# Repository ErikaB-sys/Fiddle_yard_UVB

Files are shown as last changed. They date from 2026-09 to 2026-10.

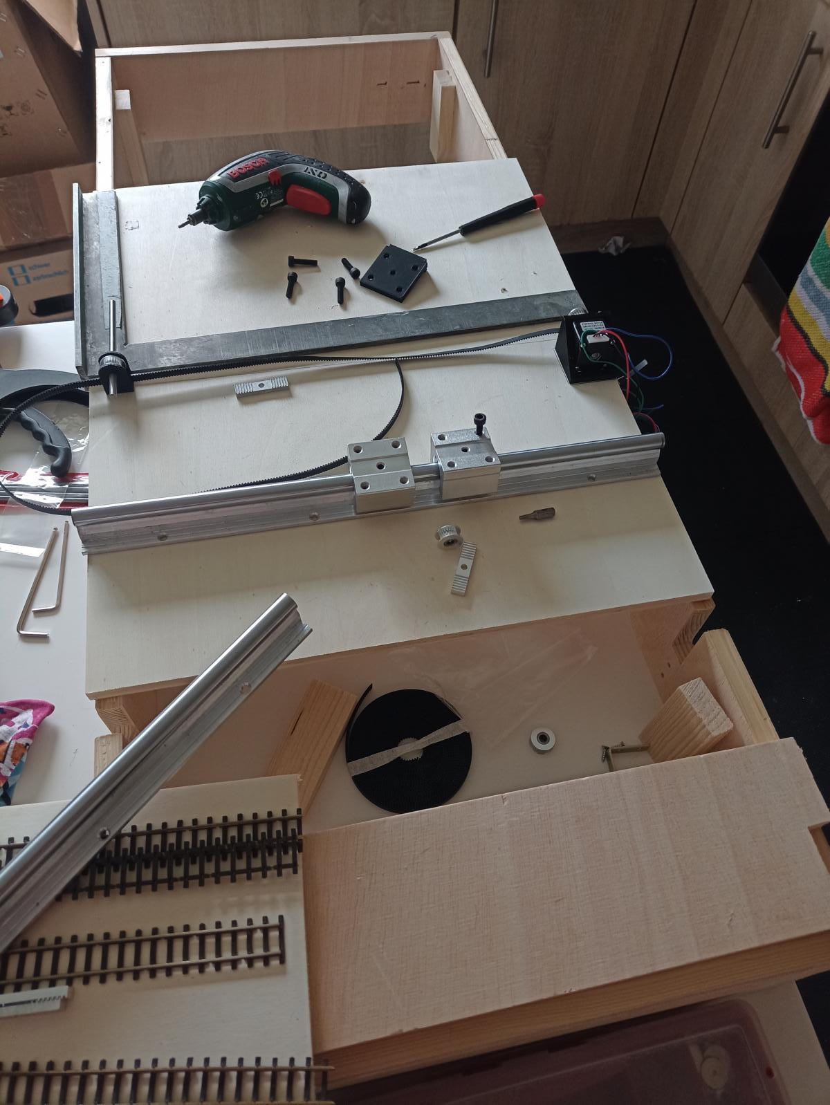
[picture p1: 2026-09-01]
Documents/Pictures/K1600/1000129678.JPG

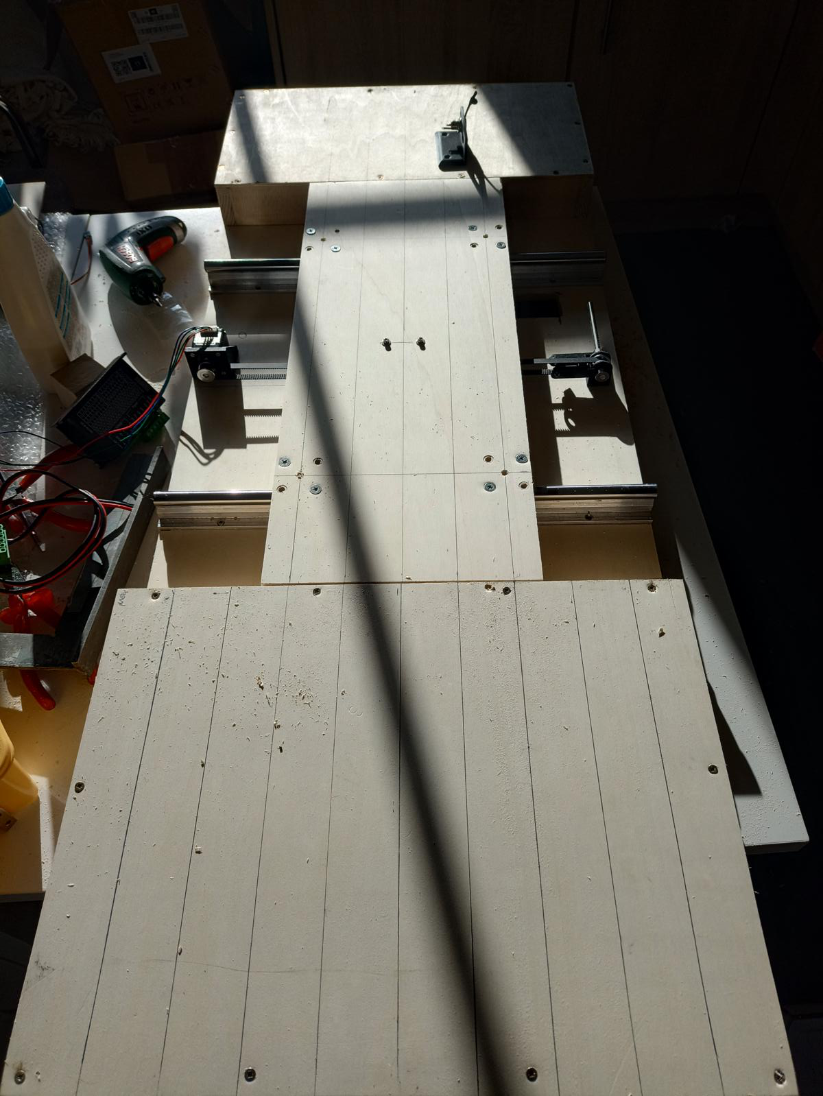
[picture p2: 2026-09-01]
Documents/Pictures/K1600/1000129823.JPG

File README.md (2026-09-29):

# Fiddle_yard_UVB
## Soft and Hard ware for a Fiddleyard with sliding platform 

- Project Language : English / german 
- Usage:  for privat use only

## Coding language 
- C
- C++

## Mechanical design
- FreeCAD 1.0

## Electronic design
- KiCad

## Documents
- PDF
- LibreOffice
- FreeMind
- Mermaid — flowcharts, state diagrams and architecture documentation
- Doxygen — investigate as code-based documentation system for source-code documentation

### Documentation concept
Investigate a documentation workflow combining:
- **Mermaid** for flowcharts, state machines and software architecture diagrams, preferably stored as source in the repository and rendered where possible.
- **Doxygen** for generating technical source-code documentation from structured comments in the C/C++ code.
- **GitHub/Markdown** as the central, version-controlled documentation layer.

The goal is to keep diagrams and technical documentation close to the actual source code and maintainable together with the project.

**Open item:** Add the Doxygen/tool reference supplied by Vincent when available.

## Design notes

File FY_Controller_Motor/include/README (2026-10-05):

This directory contains project-wide header files.

The headers are separated by responsibility:

include/
├── HW_Config.h   - fixed hardware configuration
├── FY_System.h   - FY-specific system data, states and structures
├── Firmware.h    - firmware identity data
├── Main.h        - intentionally empty
└── Protokoll.h   - UART protocol definitions

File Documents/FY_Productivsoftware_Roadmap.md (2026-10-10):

# FY Produktivsoftware – technische Roadmap

**Aktiver Entwicklungsbranch:** `FY_Command_and_Responses`  
**Basis:** aktueller, kompilierbarer Stand von `main`  
**Phasenziel:** UART-Befehle und Antworten vervollständigen, Protokoll und Handler konsistent machen und die Implementierung gezielt testen. Nach erfolgreicher Abschlussprüfung wird die Phase nach `main` gemergt.

> Arbeitsdiagramm für die schrittweise Überführung der Erkenntnisse aus dem FY_HW_TEST in die Produktivsoftware.

```mermaid
flowchart TD
    A["HW-Test Erkenntnisse<br/>#105"] --> B["Motor / Profil<br/>#104"]
    V["Firmware-Identität<br/>#107/ DONE"] -. Build-/Diagnosebasis .-> B

    B --> C["UART / Intermediate Commands<br/>#13"]
    C --> D["Erstes Positions-Command / Motor-Schnittstelle<br/>#28"]
    D --> E["Parameter / Profilwerte<br/>#106 + #104"]
    E --> F["Motorbewegung / Execution / STEP<br/>#51"]

    F -. parallel .-> T["Tests / Native<br/>#46 + PC-Tests"]
    F --> G["Motorzustand / Sicherheit<br/>#86 + #26 + #50 + #52"]
    G --> H["Sensoren<br/>#93"]
    H --> I["Referenz<br/>#85 + #94"]
    I --> J["Position / Trackmodell<br/>#11"]
    J --> K["Keyboard / LOCAL<br/>#88 + #89"]
    K --> L["Display<br/>#90"]
    K --> M["UART / Service<br/>#13 + #17 + #28 + #29 + #39"]
    L --> N["LOCAL / REMOTE<br/>#91"]
    M --> N
    M -. Service .-> S["Servicebetrieb<br/>#95"]
    N --> O["System Executive<br/>#96"]
    O --> P["Gesamtintegration<br/>#30 + Tests"]

    T -. Validierung .-> G
    T -. Validierung .-> I
    T -. Validierung .-> J
    T -. Validierung .-> P
```

## Arbeitsreihenfolge

Die Motorintegration wird bewusst in kleinen, testbaren Schritten aufgebaut. Die echte Hardware ist dabei zunächst **nicht erforderlich**; die Produktivsoftware wird auf dem Schreibtisch-Mockup entwickelt und geprüft.

1. **Firmware-Identität** als kleine Build-/Diagnosebasis festlegen.
2. **Motor-/Profil-Erkenntnisse aus dem HW-Test** übernehmen, ohne den HW-Test-Code zu kopieren.
3. **Intermediate Commands** zuerst produktiv stabilisieren. Damit wird die Kommunikation CMD → Verarbeitung → Response unabhängig von echter Motorbewegung überprüfbar.
4. **Erstes Positions-Command / Motor-Schnittstelle** einführen. Zunächst reicht die Verbindung bis zur Motorlogik bzw. zum Mockup; die vollständige STEP-Ausführung folgt später.
5. **Parameter- und Profilmodell** schrittweise festlegen. Als Startpunkt werden die im HW-Test verifizierten und veränderbaren Parameterwerte verwendet. Die endgültige Klassifizierung von Default-, Konfigurations-, Kalibrier-, Laufzeit- und Diagnosewerten erfolgt in #106.
6. **Motorbewegung / Execution / STEP** in die Produktivsoftware überführen. Die verifizierte Profilberechnung aus #104 und die STEP-Ausführung aus #51 werden dabei getrennt gehalten: Profil berechnet, Execution führt aus.
7. **Mockup vollständig gegen die Produktivschnittstellen testen.**
8. Erst wenn Kommunikation, Position, Parameter und Motor-Execution auf dem Mockup funktionieren, erfolgt der **erste Live-Test mit Steppertreiber und echter Motor-Hardware**.
9. Danach Motorzustand, Sicherheit, Sensoren und Referenz schrittweise ergänzen.
10. Erst auf diesem stabilen Kern folgen Bedienung, Service und Systemintegration.

## Arbeitsprinzip

- Die drei Command-Klassen werden bewusst nacheinander genutzt: **INTERMEDIATE → Positions-/Bewegungsauftrag → weitere ausführende Commands**.
- Kommunikation wird vor echter Motorbewegung stabilisiert.
- Das erste Positions-Command bildet die Brücke zwischen UART und Motor-Schnittstelle.
- Parameter werden zunächst aus dem HW-Test übernommen, aber ihre endgültige Struktur wird nicht vorweggenommen.
- Die reale Hardware dient erst dann als Integrationsprüfung, wenn die Produktivlogik auf dem Mockup nachvollziehbar funktioniert.
- Der Steppertreiber ist eine nachgelagerte Hardware-Schnittstelle; seine konkrete Implementierung wird nicht zum Vorab-Gegenstand der Motor-API gemacht.
- Der HW-Test-Code wird nicht kopiert.
- Übernommen werden bestätigte Anforderungen, Zustände, Abläufe, Parameter und technische Prinzipien.
- UART bleibt bei jedem Entwicklungsschritt funktionsfähig, damit der Nano weiterhin beobachtet und getestet werden kann.
- Referenzkompensation zunächst nicht erzwingen; die Architektur dafür bleibt offen.
- Parameter und EEPROM werden in #106 schrittweise klassifiziert.
- `response()` der Produktiv-UART wird im Zuge der UART-Überarbeitung konkretisiert.
- Neue Issues nur anlegen, wenn aus der Umsetzung tatsächlich eine Lücke entsteht.
- Die Firmware-Identität wird zentral gepflegt: Release-Version manuell, Builddatum/-zeit und Git-Commit automatisch aus dem Build ableiten.

## Gemeinsame Software-Komponenten und Versionierung

Gemeinsame Dateien oder Bibliotheksbestandteile zwischen HW-Test und Produktivsoftware sind grundsätzlich zulässig, wenn sie tatsächlich ein gemeinsames Verfahren oder einen gemeinsamen Mechanismus beschreiben. Das gilt insbesondere für hardwarefreie Berechnungen oder eindeutig definierte Datenstrukturen.

Dabei gilt:

- Eine gemeinsame Datei ist eine **gemeinsame Software-Komponente**, nicht automatisch Bestandteil jeder Firmware-Version.
- Änderungen an einer gemeinsamen Komponente dürfen **keine stille Verhaltensänderung** in einem anderen Projekt erzeugen.
- Die Übernahme einer geänderten gemeinsamen Komponente in eine Firmware muss deshalb **bewusst und nachvollziehbar** erfolgen.
- Die verwendete Version bzw. der konkrete Git-Stand der Komponente muss aus dem jeweiligen Projektstand nachvollziehbar sein.
- Eine Änderung der gemeinsamen Komponente wird zunächst isoliert geprüft. Erst danach wird sie in die jeweils betroffenen Firmwarebereiche übernommen.
- Wenn HW-Test und Produktivsoftware fachlich auseinanderlaufen, darf eine gemeinsame Datei aufgelöst werden. Beide Projekte erhalten dann bewusst eigene Implementierungen.
- **Submodule oder Subrepositories werden dafür nicht vorausgesetzt.** Die gemeinsame Komponente kann im selben Repository liegen; entscheidend ist die nachvollziehbare Übernahme und nicht die technische Verpackung.
- Vor einer Änderung an `FY_Common` wird daher geprüft, welche Projekte die Komponente tatsächlich verwenden und ob eine gemeinsame Weiterentwicklung noch sinnvoll ist.

Für `FY_Common/MotorProfile.h` ist damit zunächst **keine automatische gemeinsame Weiterentwicklung festgelegt**. Vor der nächsten Änderung wird geklärt, ob die Profilberechnung weiterhin eine echte gemeinsame Komponente sein soll oder ob HW-Test und Produktivsoftware an diesem Punkt bewusst getrennte Wege gehen.

## Branch- und Merge-Regel

`main` ist die maßgebliche Referenz für den aktuellen Produktivstand. Die jeweils laufende Implementierungsphase erhält einen eigenen, klar benannten Branch, der aus dem aktuellen `main` erstellt wird. Es wird nicht parallel auf mehreren Produktiv-Branches gearbeitet.

**Aktuelle Phase:** `FY_Command_and_Responses`  
**Ausgangsbasis:** der aktuelle, kompilierbare Stand von `main` mit den bewusst akzeptierten `unused`- und MISRA-Warnings.

Ziele der Phase:

1. Command- und Response-Definitionen mit der tatsächlichen Implementierung abgleichen und vervollständigen.
2. Telegrammlängen, Parameter, Handler und Fehlerantworten konsistent machen.
3. Verfügbare native Tests und gezielte Protokolltests ausführen; nicht ausgeführte Prüfungen ausdrücklich offenhalten.
4. Relevante Issues und Implementierungsstatus aktualisieren.
5. Einen kompilierbaren, überprüften Zwischenstand ohne bekannte Blocker für die abgeschlossene Phase erreichen.

Nach Abschlussprüfung wird `FY_Command_and_Responses` gezielt nach `main` gemergt. Danach wird die nächste Implementierungsphase – voraussichtlich `FY_Motor` – aus dem dann aktuellen `main` erstellt. Der bisherige Branch `FY_Controller_Motor` bleibt als historischer Entwicklungsstand erhalten und wird nicht gelöscht.

Vor jeder Übernahme werden Commit-Historie, relevante Issues und bewusste Architekturentscheidungen geprüft. Eine Abweichung zwischen Branches gilt nicht automatisch als Fehler. Bereits bewusst in `main` vorgenommene Änderungen werden respektiert; es werden nur tatsächlich relevante Unterschiede als offene Punkte gemeldet.

Vor jedem neuen Arbeitsabschnitt werden aktiver Branch und Ausgangscommit geprüft und benannt. Es wird nicht stillschweigend zwischen unterschiedlichen Branch-Ständen gewechselt.

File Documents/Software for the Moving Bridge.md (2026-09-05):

 # Software for the Moving Bridge

**Hardware:** ESP32

**Software components (under development):**

01  Architecture / State Machine
02  UART – Command Interface
03  UART – State Interface

04  Motor Control – Step/Direction/Enable
05  Movement Control – Positioning
06  Movement Control – Acceleration/Deceleration
07  Movement Control – ISR
08  Movement Control – Position Table

09  Reference Sensor
10  Limit / Border Sensor
11  Error Handling
12  Startup and Recovery

13  Button Module – Input Handling
14  Button Module – Commands

15  OLED – Basic Driver
16  OLED – Motor Position
17  OLED – Track Position
18  OLED – State
19  OLED – Error Screen

20  Configuration Storage

21  Web Interface – Status
22  Web Interface – Movement
23  Web Interface – Configuration

24  MQTT – Topic Structure
25  MQTT – Command
26  MQTT – State

27  DCC Detection [OPTIONAL]
28  Track Control [OPTIONAL]

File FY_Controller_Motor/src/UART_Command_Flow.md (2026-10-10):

# UART Commands – Ablauf und Antwortbedingungen

Referenz für die Protokollabstimmung in [Issue #58](https://github.com/ErikaB-sys/Fiddle_yard_UVB/issues/58).
Die Übersicht unterscheidet bereits implementierte Antwortpfade von noch offenen Handlern.

## Zentrale Übersicht

```mermaid
flowchart TD
    A[ASCII-Eingabe] --> B[BabelFish dekodiert Command]
    B --> C{Command erkannt?}
    C -- Nein --> N1[NACK: ungültige Eingabe]
    C -- Ja --> D[Validierung: Command-ID, DATA-Länge, CRC]
    D --> E{Validierung erfolgreich?}
    E -- Nein --> N2[NACK: ungültiges Telegramm]
    E -- Ja --> F{Command-Typ}
    F -- IMMEDIATE --> G[GET / HELP / FIRMWARE Handler]
    G --> R1[Passende STATUS-Antwort]
    F -- EXECUTE --> H{System Busy?}
    H -- Ja --> N3[NACK mit Command-ID]
    H -- Nein --> I{Execute-Command}
    I -- SET_MODE --> M[SET_MODE Handler]
    M --> M1{Daten und Zustand gültig?}
    M1 -- Ja --> ACK[ACK mit Command-ID]
    M1 -- Nein --> N4[NACK mit Command-ID]
    I -- Andere Execute-CMDs --> T[Antwortverhalten je Handler prüfen]
    F -- PRIORITY --> P[Priority-Handler]
    P --> R2[Antwort gemäß Command-Definition]
```

## SET_MODE – Detailablauf

```mermaid
flowchart TD
    A[CMD_SET_MODE, DATA-Länge 2] --> B{Systemstatus, Keyboard und Motor verfügbar?}
    B -- Nein --> N[NACK, keine Zustandsänderung]
    B -- Ja --> C{System Busy oder Motor bewegt sich?}
    C -- Ja --> N
    C -- Nein --> D{DATA = 55 AA?}
    D -- Ja --> L[System Mode = LOCAL\nKeyboard mirrors system mode]
    D -- Nein --> E{DATA = AA 55?}
    E -- Ja --> R[System Mode = REMOTE\nKeyboard mirrors system mode]
    E -- Nein --> N
    L --> ACK[ACK mit Command-ID]
    R --> ACK
```

## SET_MODE – Bedingungen

| Bedingung | Antwort | Zustandsänderung |
|---|---|---|
| Erforderliches Modul fehlt | NACK | keine |
| System meldet Busy | NACK | keine |
| Motor bewegt sich | NACK | keine |
| DATA `55 AA` | ACK | `FY_SystemStatus_t.mode = LOCAL`; keyboard mirrors mode |
| DATA `AA 55` | ACK | `FY_SystemStatus_t.mode = REMOTE`; local movement/OK inputs locked, STOP remains available |
| Anderes DATA-Muster | NACK | keine |

- Command-ID: `CMD_SET_MODE = 0x26` (bisherige SET_LOCAL-ID weiterverwendet).
- DATA-Länge: 2 Byte.
- `CMD_SET_LOCAL` und `CMD_SET_REMOTE` entfallen; die alte ID `0x2A` wird nicht mehr verwendet.
- ACK (`0x60`) und NACK (`0x70`) enthalten jeweils die Command-ID als ein DATA-Byte; die CRC folgt wie üblich.
- Die maßgebliche Betriebsart liegt in `FY_SystemStatus_t.mode`; das Keyboard spiegelt sie für Anzeige und lokale Eingabesperre.
- SET_MODE schaltet den Motor nicht ein und startet keine Bewegung.
- Der Wechsel ist nur im Stillstand zulässig.

## Noch offene Handler

Die zentrale Übersicht ist keine Behauptung, dass alle Command-Handler bereits vollständig implementiert sind. STOPP bleibt gemäß aktueller Arbeitsabsprache zurückgestellt. Die Antwortpfade der übrigen Execute-Commands werden zusammen mit deren tatsächlicher Implementierung abgeglichen. GET-Antworten richten sich nach den vorhandenen Response-Definitionen und werden mit den Modulen vervollständigt.

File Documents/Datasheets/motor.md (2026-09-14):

Motor:
  Type: Nema 17
  Manufacturer:  	Iverntech 

Electrical:
  Rated voltage: 3.8 V DC
  Rated current:  0.8 A
  Phase resistance: 4,8Ohm 10%
  Phase inductance: 2,8 mH 20%

Mechanical:
  Step angle:       1,8°
  Holding torque:   min. 6.5Ncm
  Rotor inertia:    7,5g gcm^²

Speed/Torque:
  Torque curve:          ?
  Max recommended speed: ? 	28 Umdrehungen pro Minute

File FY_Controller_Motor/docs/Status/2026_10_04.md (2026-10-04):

# FY UVB – Projektstatus

**Stand: 04.10.2026**

## 1. Management Summary

Seit dem letzten Status vom **25.09.2026** hat sich der Schwerpunkt erneut verschoben:

> **Die Hardware-Testsoftware #84 ist abgeschlossen. Die reale Hardware funktioniert grundsätzlich. Der nächste Hardware-Meilenstein ist jetzt der Vergleich mit dem neuen Motor.**

Der Hardware-Smoke-Test hat damit seine Aufgabe erfüllt: Sensoren, ENABLE/DIR/STEP, Timer1-Testbetrieb und die grundlegende Motor-/Treiberkette sind praktisch nachgewiesen.

Parallel hat sich der **Produktivcode deutlich weiterentwickelt**, vor allem auf der UART-Seite:

- UART #13 ist inzwischen **geschlossen**.
- Command-Telegramme, Längenprüfung, CRC und ResponsePending/Response-Fluss sind wesentlich weiter.
- Die Verbindung **UART → MotorJob → Motor.setJob()** ist als Architektur vorhanden.
- Die fachliche Trennung **validateCommand() → prepare...() → setJob()** ist inzwischen festgelegt.
- calcProfile() #23 ist abgeschlossen.
- Die aus dem HW-Test gewonnenen Erkenntnisse werden jetzt gezielt in die Produktivsoftware überführt (#104/#105).
- Firmware-Identität #107 ist abgeschlossen.
- Ein neues Parameter-/Kalibrierungsmodell #106 ist angelegt.
- Die neue Motorvariante #109 und die per Arduino schaltbare Microstep-Stufe #110 sind zusätzliche Hardware-Randbedingungen, aber **kein Grund, die Motorarchitektur erneut aufzureißen**.

Der wesentliche Befund für die Roadmap lautet:

> **Die bisherige Roadmap ist fachlich weiterhin richtig, aber die Reihenfolge muss von einer linearen UART→Motor-Entwicklung zu einer parallelen Integrations-Roadmap angepasst werden.**

UART ist nicht mehr der Engpass. Der Engpass ist jetzt eindeutig:

```text
MotorJob
   ↓
prepare...
   ↓
State Machine
   ↓
Timer1 / STEP
   ↓
Position
   ↓
Reference
```

Danach folgt die Systemintegration.

---

## 2. Status nach Hauptmodulen

| Modul / Bereich | Status | Bewertung |
|---|---|---|
| FY_HW_Test #84 | 🟢 abgeschlossen | Hardware-Smoke-Test erfüllt seinen Zweck |
| Sensorhardware | 🟢 | Lichtschranken mechanisch montiert und praktisch bestätigt |
| Motor-Hardwarepfad | 🟢/🟡 | Motor läuft grundsätzlich; Laufkultur/Strom/Spannung werden noch untersucht |
| neuer Motor #109 | 🟡 | bestellt, Halter wird vorbereitet, Vergleichstest folgt |
| Microstepping #110 | 🟡 | neue Platine kann künftig umschalten; 1/4 bleibt zunächst Referenz |
| UART #13 | 🟢 abgeschlossen | Empfang, Validierung, CRC und Response-Fluss weitgehend fertig |
| UART Robustheit #17 | 🟡 | verbleibende Detail-/Sicherheitsfragen |
| UART → Motor #28 | 🟡 | Schnittstelle vorhanden, vollständige Laufzeitintegration fehlt |
| calcProfile() #23 | 🟢 abgeschlossen | mathematische Profilberechnung produktiv vorhanden |
| HW-Erkenntnisse → Produktivcode #104/#105 | 🟡 | laufende Übergangsphase |
| Parameter/Kalibrierung #106 | 🟡 | neu angelegt, vorläufige Grundlage |
| Motor ON/OFF #86 | 🟡 | fachlich definiert, produktive Umsetzung offen |
| prepare... #24 | 🟡 | fachlich spezifiziert, produktive Umsetzung als nächster Motorblock |
| State Machine #50 | 🔴 | noch nicht fertig |
| Timer1 / STEP / ISR #51 | 🔴 | Architektur definiert, produktiver Executor offen |
| Position / Status #52 | 🔴 | Schnittstelle definiert, produktive Positionsführung offen |
| Reference #27 | 🟢 fachlich / 🔴 technisch | Spezifikation abgeschlossen, Implementierung offen |
| Switches #93 | 🟡 | Rohzugriff/ISR-Architektur definiert |
| System Executive #96 | 🟡 | Architektur angelegt, Implementierung noch nach Motorgrundfunktion |
| Keyboard / OLED | 🟢 Basis / 🟡 Integration | Modul vorhanden, Systemanbindung offen |
| POR #94 | 🟢 spezifiziert/geschlossen | Systemablauf definiert, technische Abhängigkeiten bestehen noch |
| Tests #59/#60–#71 | 🟡 | Struktur vorhanden, konkrete Implementierung folgt mit den Produktivblöcken |
| Dokumentation | 🟢/🟡 | gute Basis, muss mit dem Produktivstand synchronisiert bleiben |

---

## 3. Hardware: #84 ist fertig

Der separate **FY_HW_Test** hat seinen Zweck erfüllt.

Nachgewiesen sind insbesondere:

- Controller-/I²C-Hardware
- Taster und LEDs
- OLED
- Lichtschranken / Endsensoren
- Referenzfahnen
- ENABLE
- DIR
- STEP
- Timer1-basierte Testbewegung
- Endschalter-Sperre im Testbetrieb
- Motorbetrieb ohne mechanische Kopplung
- grundlegende mechanische Funktion

Damit ist #84 **nicht mehr Teil der eigentlichen Produktentwicklungs-Roadmap**.

Der Testcode bleibt als Werkzeug erhalten, aber wir müssen dort nicht mehr künstlich weiterentwickeln.

---

## 4. Hardware-Kurzradar

Die verbleibenden Hardwarefragen sind bewusst klein.

### Neuer Motor #109

Der neue Motor wird zunächst gegen den bisherigen Aufbau getestet.

Geplant:

```text
Motorhalter
   ↓
neuer Motor
   ↓
gleicher Treiber
   ↓
etwas höherer Strom
   ↓
ggf. etwas höhere Versorgungsspannung
   ↓
Laufverhalten vergleichen
```

Ziel ist zunächst nicht eine endgültige Optimierung, sondern die Frage:

> **Bringt der stärkere Motor bei sinnvoller Ansteuerung tatsächlich einen praktischen Vorteil?**

### Microstepping #110

Die neue Platine erlaubt später die Umschaltung der Microstep-Stufe.

Für die Produktentwicklung bleibt zunächst:

**1/4 Schritt = Referenzkonfiguration.**

Andere Stufen sind zunächst Experimentier-/Vergleichswerte.

Damit muss die Motorlogik **nicht** an eine einzelne Microstep-Hardwareverdrahtung gekoppelt werden.

---

## 5. UART – deutlicher Fortschritt

Hier hat sich die Lage gegenüber dem letzten Status stark verändert.

### UART #13

**🟢 abgeschlossen**

Die wichtigsten Schritte wurden inzwischen umgesetzt:

- Command-Längen korrigiert
- Command-Validierung vervollständigt
- CRC-Prüfung eingebunden
- Validation-Status erhalten
- ResponsePending-Fluss fertiggestellt
- Send-Response-Mechanismus praktisch erprobt

Damit ist UART nicht mehr der technische Hauptengpass.

### Was noch bleibt

#17 bleibt als Robustheits-/Feinschliff-Thema offen.

Außerdem muss die tatsächliche Rückmeldung des Motors später mit den Motorzuständen verbunden werden:

```text
Motor
  ↓
Status / DONE / ERROR
  ↓
UART Response
```

Das ist aber **Integrationsarbeit**, keine neue UART-Grundarchitektur.

---

## 6. UART → Motor

Die ursprüngliche Roadmap hatte hier einen linearen Ablauf:

```text
UART
 ↓
MotorJob
 ↓
Motor
```

Das ist inzwischen als Schnittstelle vorhanden.

Die wichtigere Erkenntnis aus der Arbeit der letzten Tage ist die saubere Verantwortungsverteilung:

```text
UART
 ↓
validateCommand()
 ↓
MotorJob
 ↓
prepare...()
 ↓
setJob()
 ↓
Motor
```

### validateCommand()

Prüft das Telegramm formal: Command, Länge, CRC, formale Datenvalidität.

### prepare...()

Prüft die fachliche Ausführbarkeit: Motor ON, Job, Ziel, Referenz, Grenzen, Profil.

### setJob()

Übernimmt nur einen bereits zulässigen, ausführbaren Auftrag.

> **Diese Trennung ist eine wichtige Architekturentscheidung und sollte nicht wieder aufgeweicht werden.**

---

## 7. Motor – der aktuelle Hauptblock

### #23 calcProfile()

**🟢 abgeschlossen**

Die Profilberechnung ist inzwischen ein echter Produktivbaustein.

Die sechs Segmente bleiben:

```text
ACC1 → ACC2 → KONST → BRE1 → BRE2 → POSI
```

Die Profilmathematik bleibt vollständig außerhalb der ISR.

Die HW-Erkenntnisse haben das Modell inzwischen zusätzlich konkretisiert:

- 1/4 Microstepping als aktuelle Referenz
- obere praktische STEP-Geschwindigkeit etwa 1000 Steps/s
- keine Sprünge auf VMAX innerhalb des Profils
- unabhängige Rampenintervalle
- Profil vollständig vor Bewegungsstart berechnen

Das ist genau der Zweck von #104: **HW-Erkenntnisse übernehmen, ohne HW-Testcode in den Produktivcode zu kopieren.**

---

## 8. #104 / #105 – Übergang HW-Test → Produktivsoftware

Das ist momentan ein **Brückenbereich**, kein eigenständiges Produktmodul.

#105 definiert sinnvoll die vier Kategorien:

- ANPASSEN
- ÜBERNAHME
- NEU
- NICHT ÜBERNEHMEN

Diese Arbeitsweise passt weiterhin.

Besonders wichtig:

> Der HW-Test wird nicht zur zweiten Produktivarchitektur.

Wir übernehmen nur die bestätigten Parameter, Randbedingungen, Zustände, Messwerte und Anforderungen.

Die Test-/Diagnosemechanik bleibt dort, wo sie hingehört.

---

## 9. #24 prepare... – nächster konkreter Motorblock

**🟡 → nächster Umsetzungsschritt**

Die fachliche Reihenfolge steht:

```text
Motor ON?
   ↓
Job
   ↓
Ziel bestimmen
   ↓
Ziel plausibilisieren
   ↓
Referenz prüfen
   ↓
Grenzen prüfen
   ↓
TargetPosition
   ↓
calcProfile()
   ↓
TimerValid
```

Damit ist die Aufgabe inzwischen deutlich kleiner als noch im Status vom 25.09.

Die Profilmathematik ist fertig. Die fachlichen Regeln sind festgelegt.

Jetzt geht es tatsächlich um die Implementierung der vier Prepare-Funktionen und CheckBorder().

---

## 10. #86 Motor ON/OFF

**🟡 fachlich fertig, Implementierung offen**

Die Trennung bleibt verbindlich:

```text
motorEnabled
referenceValid
```

Motor ON bedeutet nur: Motor darf elektrisch betrieben werden.

Motor ON bedeutet **nicht**: Motor ist referenziert.

Motor OFF führt dagegen zum Verlust der gültigen Referenz.

Das ist inzwischen eine klare Voraussetzung für #24.

---

## 11. #50 State Machine

**🔴 offen**

Die State Machine ist jetzt der nächste größere Motorblock.

Sie soll nicht die Bewegungsmathematik enthalten, sondern orchestrieren:

```text
MotorJob
   ↓
prepare
   ↓
MOVING
   ↓
Timer1
   ↓
STOP_BY_PROFILE
        oder
STOP_BY_SWITCH
   ↓
Folgezustand
```

Die bereits festgelegte Trennung zwischen physischem Ereignis und fachlicher Fehlerbewertung bleibt dabei wichtig.

---

## 12. #51 Timer1 / STEP / ISR

**🔴 offen – aber jetzt klar spezifiziert**

Die ISR ist inzwischen fachlich gut eingegrenzt.

**Darf:** STEP erzeugen, DIR ausgeben, Position verändern, Profilsegment wechseln, Endschalter unmittelbar berücksichtigen, physischen Stop melden.

**Darf nicht:** Profil berechnen, UART bedienen, fachliche Fehlerdiagnose durchführen, komplexe Systemlogik ausführen.

Damit ist #51 kein Architekturproblem mehr.

Es ist jetzt eine **Implementierungsaufgabe**.

---

## 13. #52 Position

**🔴 offen**

Die Positionsführung wird direkt mit #51 gekoppelt:

```text
logische Richtung
      ↓
STEP
      ↓
Position +/- 1
```

Wichtig bleibt:

**Die elektrische DIR-Pinpolarität bestimmt nicht die mathematische Bewegungsrichtung.**

Die Zuordnung wird konfigurierbar gehalten.

---

## 14. Reference #27

**🟢 Spezifikation abgeschlossen / 🔴 technische Umsetzung offen**

Die Referenzfahrt ist nicht mehr „noch zu überlegen“.

Sie ist fachlich definiert:

- kurze und lange Referenzierung
- gemeinsame State Machine
- linke/rechte Endlage
- Referenzfahne
- langsame Referenzanfahrten
- Messung aus beiden Richtungen
- Toleranzbewertung
- unabhängige Schritt-/Zeitlimits
- Kalibrierdaten

Damit ist die Arbeit jetzt überwiegend **Implementierung**.

Die reale Sensorhardware ist bereits vorhanden und geprüft.

---

## 15. #106 Parameter- und Kalibrierungsmodell

**🟡 neu / sinnvoll**

Dieses Issue ist eine direkte Konsequenz aus dem HW-Test.

Wir haben inzwischen echte Messwerte und müssen unterscheiden zwischen:

| Kategorie | Beispiel |
|---|---|
| fester Systemwert | Track-Anzahl |
| Default | initiale VMIN/VMAX |
| Konfiguration | veränderbarer Parameter |
| Messwert | Referenzmessung |
| Kalibrierwert | gültige Referenzdaten |
| Laufzeitwert | aktuelle Position |
| Diagnosewert | VMAX_REACHED |

Das Issue sollte **nicht** vorzeitig in eine große EEPROM-Architektur ausarten.

Die fachliche Klassifizierung kommt zuerst.

---

## 16. Systemintegration – neue Gewichtung

Hier hat sich die Roadmap am stärksten verändert.

Früher war der Gedanke:

```text
UART
 ↓
Motor
 ↓
System
```

Heute ist klarer:

```text
          UART
            │
Keyboard ─ System ─ Motor
            │
         Switches
```

und im Motor selbst:

```text
System
  ↓
MotorJob
  ↓
prepare
  ↓
Timer1 ISR
```

Das neue **System Executive #96** ist deshalb sinnvoll.

ABER:

> **#96 ist kein Grund, die Motorimplementierung jetzt zu unterbrechen.**

Der Motor muss erst eine saubere ausführbare Einheit sein.

Danach kann das System Executive die vorhandenen Module zusammenführen.

---

## 17. Keyboard / POR

Hier ist die Situation ebenfalls günstiger als im letzten Status.

#94 **POR – Systemstart, LOCAL und Referenzlauf über Keyboard** ist inzwischen geschlossen.

Das bedeutet nicht, dass der komplette Ablauf technisch schon auf der Hardware läuft.

Es bedeutet:

> **Der gewünschte Systemablauf ist entschieden.**

Damit können wir später die vorhandenen Keyboard-/OLED-Bausteine gegen die tatsächlichen Motorzustände verdrahten.

Das ist genau die richtige Reihenfolge.

---

## 18. Tests – neue Strategie

Die Test-Issues #60–#71 bleiben sinnvoll.

Aber wir sollten sie nicht mehr als riesigen separaten Block vor uns herschieben.

Stattdessen:

```text
Produktivfunktion
      ↓
kleiner Test
      ↓
nächste Produktivfunktion
      ↓
Integrationstest
```

Insbesondere:

- #51 → Timer-/STEP-Test
- #52 → Positions-/Status-Test
- #50 → State-Machine-Test
- #28/#29 → UART/Motor-Integration
- #59 → UART-Modultests

Damit wird die Testarbeit wieder **Teil der Implementierung** statt ein zweites Projekt.

---

## 19. Roadmap-Bewertung

### 🟢 Was weiterhin stimmt

Die grundsätzliche Architektur stimmt weiterhin:

```text
UART / Keyboard
       ↓
    MotorJob
       ↓
    prepare
       ↓
  calcProfile
       ↓
   State Machine
       ↓
   Timer1 / ISR
       ↓
    Position
       ↓
   Reference
       ↓
 System
```

Auch die Trennung **Hardware-Test ≠ Produktivsoftware** ist weiterhin richtig.

### 🟡 Was geändert werden muss

Die Roadmap darf **nicht mehr als lineare Liste „erst UART, dann Motor“** betrachtet werden.

UART ist inzwischen weitgehend fertig.

Der neue Schwerpunkt ist:

### Phase A – Motor ausführbar machen

1. #24 prepare...
2. #86 Motor ON/OFF
3. #50 State Machine
4. #51 Timer1 / STEP / ISR
5. #52 Position

### Phase B – Referenz und Kalibrierung

6. #27 Reference
7. #85 Referenzkorrektur
8. #106 Parameter/Kalibrierung

### Phase C – System

9. #96 System Executive
10. Keyboard/POR-Anbindung
11. UART ↔ Motor ↔ System
12. ACK/BUSY/DONE/ERROR im echten Lauf

### Phase D – Verifikation

13. Modultests
14. Hardware-/Referenztest
15. Track-Betrieb
16. Gesamtintegration

---

## 20. Was NICHT auf die kritische Route gehört

Folgende Themen bleiben bewusst Radar/Backlog:

- ESP32
- Webinterface
- komplexe Diagnose
- Bewegungsanimation
- Step-Servicebetrieb #95
- umfangreiche OLED-Menüs
- BELT_SENSOR
- weitere Abstraktionsschichten
- perfekte Fehlerhistorie

Sie können später sinnvoll werden.

**Sie blockieren den Motor aber nicht.**

---

## 21. Aktuelle kritische Kette

```text
             🟢 UART
                │
                ▼
          🟢 MotorJob
                │
                ▼
          🟡 prepare...
                │
                ▼
          🟢 calcProfile
                │
                ▼
          🔴 State Machine
                │
                ▼
          🔴 Timer1 / ISR
                │
                ▼
          🔴 Position
                │
                ▼
          🔴 Reference
                │
                ▼
          🟡 System
                │
                ▼
          🔴 Gesamtintegration
```

Und daneben:

```text
🟢 Hardware-Smoke-Test
       │
       ├── 🟢 Sensoren
       ├── 🟢 STEP/DIR/ENABLE
       ├── 🟢 Motor grundsätzlich
       │
       └── 🟡 neuer Motor / Parametervergleich
```

---

## 22. Managerfragen – Antworten

### Sind wir auf Kurs?

**Ja.**

Nicht auf dem ursprünglichen Zeitplan im Sinne einer starren Reihenfolge, aber auf der technischen Roadmap.

### Gibt es ein Architekturproblem?

**Nein.**

Im Gegenteil: Die Verantwortlichkeiten sind inzwischen klarer als vor zwei Wochen.

### Gibt es einen technischen Engpass?

**Ja: Motor Execution.**

```text
prepare → State Machine → Timer1 → Position
```

### Ist UART noch kritisch?

**Nein.**

UART ist inzwischen eine belastbare Basis. Die noch offenen Punkte sind überwiegend Integration und Robustheit.

### Ist die Hardware ein Risiko?

**Nur noch begrenzt.**

Der Motor läuft grundsätzlich. Der neue Motor wird jetzt zeigen, ob wir bei Drehmoment/Laufkultur noch etwas verbessern können.

### Müssen wir die Roadmap neu schreiben?

**Nicht komplett.**

Wir müssen sie **neu gewichten und entlinearisieren**.

### Was ist der nächste echte Meilenstein?

> **Eine produktive Bewegungsanforderung läuft von MotorJob über prepare und Profil bis zu einem echten STEP-/Positionsablauf.**

Das ist der nächste große grüne Haken.

---

## 23. Gesamtfazit

Der Projektstand hat sich seit dem letzten Status deutlich verändert.

Am 25.09. war die zentrale Frage:

> **„Kann die Hardware überhaupt laufen?“**

Heute lautet sie:

> **„Wie bringen wir die bereits definierte Produktivmotorlogik jetzt kontrolliert bis zum ersten echten Bewegungsauftrag?“**

Das ist ein qualitativer Fortschritt.

Die Hardware-Testphase ist praktisch abgeschlossen.

UART ist von einem offenen Entwicklungsblock zu einer weitgehend fertigen Kommunikationsbasis geworden.

Die Produktivsoftware hat mit calcProfile() ihren ersten wirklich fertigen Motorbaustein.

Die fachliche Architektur für Prepare, Motorzustand, State Machine, Timer1 und Reference ist weitgehend entschieden.

Damit ist die Roadmap weiterhin tragfähig.

**Die Änderung besteht vor allem darin, dass wir jetzt nicht mehr „UART fertig machen und dann Motor“ arbeiten, sondern den Motor als nächsten Kernpfad fertigstellen und anschließend UART, Keyboard und System Executive darum integrieren.**

Der nächste sinnvolle Arbeitsschritt ist daher sehr unspektakulär:

**#24 – prepare... fertig machen.**

Danach wird es mit #50/#51 erstmals richtig interessant: Dann bekommt unser Produktivcode nämlich die Chance, genau das zu tun, was der Hardwaretest bereits kann – **einen Motor kontrolliert bewegen.**

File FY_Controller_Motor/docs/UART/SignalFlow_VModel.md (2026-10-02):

# UART / Motor – Signal Flow V-Model

Dieses Diagramm beschreibt den Signal- und Funktionsfluss der produktiven Firmware.
Es ist bewusst als wachsende Arbeitsdokumentation angelegt: Mit jedem abgeschlossenen
Arbeitsschritt wird der betreffende Abschnitt präzisiert.

Der Fußpunkt des V ist die Timer1-ISR. Links läuft der Eingang bis zur Ausführung
hinunter, rechts entsteht daraus wieder der Status-/Antwortweg nach oben.

## V-Modell

```mermaid
flowchart TB

    subgraph LEFT["Eingang / Auftrag"]
        L0["Host / ESP32 / Terminal"]
        L1["Serial RX"]
        L2["UART::receive()"]
        L3["BabelFish::process()\nASCII → Binär + CRC erzeugen"]
        L4["CommandBuffer"]
        L5["UART::validateCommand()\n1. CMD-ID\n2. Telegrammlänge\n3. CRC"]
        L6["decodeCommand()\nCommand seiner Verarbeitung zuordnen"]
        L7["SetCommand() / MotorJob_t"]
        L8["Motor::prepare...()\nMotorseitige Ausführbarkeit"]
        L9["Motor::setJob()\nvaliden Job übernehmen"]
        L10["calcProfile()"]
    end

    subgraph RIGHT["Antwort / Ergebnis"]
        R10["Motorzustand / Ergebnis"]
        R9["ResponseBuffer"]
        R8["UART::sendResponse()"]
        R7["Serial TX"]
        R6["Host / ESP32"]
    end

    L0 --> L1 --> L2 --> L3 --> L4 --> L5 --> L6 --> L7 --> L8 --> L9 --> L10
    L10 --> ISR["Timer1 ISR\nSTEP / Position / Profil"]
    ISR --> R10 --> R9 --> R8 --> R7 --> R6

    style ISR stroke-width:3px
```

## Arbeitsprinzip

### Linke Seite – Eingang

Die linke Seite wird von oben nach unten schrittweise fertiggestellt:

1. UART-Empfang
2. BabelFish: ASCII → Binärtelegramm und CRC erzeugen; keine semantische Command-Validierung
3. `validateCommand()`: Command-ID, Telegrammlänge und CRC prüfen; später weitere formale Telegrammprüfungen
4. Command-Zuordnung und Behandlung
5. Motorvorbereitung
6. `setJob()`
7. Profilberechnung
8. ISR-Ausführung

### Fußpunkt – ISR

Die ISR ist der Ausführungskern des V:
- STEP erzeugen
- Position fortschreiben
- Profilsegment ausführen
- Endbedingungen erkennen

Die ISR entscheidet nicht über die Bedeutung eines UART-Kommandos.

### Rechte Seite – Antwort

Die rechte Seite wird aufgebaut, sobald Ausführung und Ergebnisse definiert sind:
- Motorzustand / Ergebnis
- Response-Daten
- `sendResponse()`
- Serial TX
- Rückmeldung an Host / ESP32

## Aktueller Arbeitsstand

| Abschnitt | Status |
|---|---|
| UART → BabelFish → CommandBuffer | erledigt |
| Command-Lifecycle / UART Busy | erledigt |
| Command-ID prüfen | vorhanden |
| Telegrammlänge prüfen | vorhanden |
| **CRC in `validateCommand()` prüfen** | **nächster Arbeitsschritt** |
| Command-Zuordnung / Behandlung | danach |
| MotorJob / Motor-Schnittstelle | danach |
| Profil / ISR-Anbindung | später |
| Antwortweg vollständig definieren | wird ergänzt |

## Dokumentationsregel

Dieses Diagramm ist keine zweite Protokollspezifikation. Die konkreten Command-Definitionen
bleiben in `Protokoll.h`, die Implementierung bleibt in den jeweiligen Modulen.

Das Diagramm dokumentiert ausschließlich:
- welche Funktion als Nächstes aufgerufen wird
- welche Aufgabe sie besitzt
- welche Daten dabei weitergegeben werden
- wo im V-Modell der aktuelle Entwicklungsstand liegt.

Bei längeren Unterbrechungen soll damit ohne erneutes Durcharbeiten des gesamten Codes
erkennbar sein, wo der Signalfluss zuletzt abgeschlossen wurde.

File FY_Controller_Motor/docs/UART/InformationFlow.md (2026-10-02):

# UART – Information Flow

This document describes the information path through the productive UART architecture.

It is intentionally a **flow document**, not a second protocol specification. Command definitions remain in Protokoll.h; module behaviour remains in the respective modules.

## 1. End-to-end flow

```mermaid
flowchart LR
    A["Host / Terminal<br/>ASCII command"] --> B["Serial"]
    B --> C["UART::receive()"]
    C --> D["BabelFish"]

    D -->|ASCII → binary| E["CommandBuffer.command"]
    D -->|invalid line| X["CMD_INVALID"]

    E --> F["validateCommand()"]
    F -->|invalid| Y["DATA_INVALID"]
    F -->|valid| G["commandReady"]

    G --> H["UART::update()"]
    H --> I["decodeCommand()"]

    I -->|IMMEDIATE| J["Status / information handler"]
    I -->|EXECUTE| K["SetCommand()"]
    I -->|PRIORITY| L["Priority handler"]

    K --> M["Motor::setJob()"]
    M --> N["Motor"]

    J --> O["ResponseBuffer"]
    L --> O
    M --> O
    X --> P["NACK"]
    Y --> P

    O --> Q["sendResponse()"]
    P --> Q
    Q --> R["Serial TX"]
    R --> A
```

## 2. Where errors belong

```mermaid
flowchart TD
    A["ASCII / transport"] --> B["BabelFish"]
    B -->|syntax / command text invalid| C["CMD_INVALID"]

    B --> D["Binary command"]
    D --> E["UART validation"]
    E -->|telegram data invalid| F["DATA_INVALID"]

    E --> G["Command accepted by UART"]
    G --> H["Command dispatch"]

    H --> I["System / Motor preconditions"]
    I -->|not allowed| J["Command rejection / error"]

    I --> K["Motor execution"]
    K -->|runtime fault| L["Execution / system error"]

    J --> M["Response"]
    L --> M
```

The important architectural distinction is:

- **BabelFish errors** concern the textual command representation.
- **UART validation errors** concern the decoded command and its telegram definition.
- **System / Motor errors** concern whether a valid command may be executed.
- **Execution errors** concern faults occurring after execution has started.

These categories can later be mapped to the system-wide error definitions without changing the information flow.

## 3. Command lifecycle

```mermaid
stateDiagram-v2
    [*] --> Receive
    Receive --> CommandReady: complete / invalid line
    CommandReady --> Processing
    Processing --> Receive: response sent

    note right of CommandReady
        UART mailbox locked
        No second command accepted
    end note
```

This lifecycle is deliberately independent of the Motor state.

**UART busy** means only that one command is currently owned by the UART command lifecycle. It is not the same as FY_SystemState_t::Busy or MotorState_t::MOVING.

## 4. Architectural invariants

1. UART::receive() is the single owner of Serial input.
2. BabelFish processes characters supplied by UART; it does not own Serial.
3. The existing CommandBuffer remains the command hand-off point.
4. commandReady prevents overwriting a command while it is being processed.
5. Invalid commands follow the same lifecycle and release the UART afterwards.
6. decodeCommand() dispatches; it does not become a second Motor implementation.
7. Motor-specific execution remains in the Motor module.
8. No additional intermediate command class is introduced.

## 5. Related documentation

- ReceiveFlow.md – character reception and command lifecycle
- SetCommandFlow.md – UART → Motor job hand-off
- ClassDiagram.md – module relationships
- ../System/ModuleStates.md – system and module states
- ../System/FY_System_Executive.md – overall system scheduling

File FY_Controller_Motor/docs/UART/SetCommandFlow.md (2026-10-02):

# UART – SetCommand(...) Flow

SetCommand() is the existing UART-to-Motor hand-off for commands that become MotorJob_t.

```mermaid
flowchart TD
    A["Decoded execute command"] --> B["UART::SetCommand()"]
    B --> C["Check module / motor context"]
    C -->|missing| D["Return false"]
    C -->|available| E["Create MotorJob_t"]
    E --> F["Copy command + data"]
    F --> G["Motor::setJob()"]
    G --> H{Job accepted?}
    H -->|No| I["Return false"]
    H -->|Yes| J["Return true"]
```

## Responsibility boundary

```mermaid
flowchart LR
    U["UART"] -->|validated CommandBuffer| S["SetCommand()"]
    S -->|MotorJob_t| M["Motor::setJob()"]
    M -->|accepted / rejected| S
    S --> U
```

SetCommand() does not start the motor directly and does not inspect the internal motor profile or movement state. Those decisions belong to the Motor module.

### Important distinction

SetCommand() returning true means that the Motor module accepted the job.

It does **not** mean that physical movement has already completed.

The exact rejection reason and the system-wide error mapping are handled separately by the command/error architecture.

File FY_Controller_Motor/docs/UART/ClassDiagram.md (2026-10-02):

# UART – Class Diagram

Architecture view of the UART module, BabelFish and the hand-off to the Motor module.

```mermaid
classDiagram
    class UART {
        +begin(context, modules)
        +update()
        -receive()
        -validateCommand()
        -decodeCommand()
        -sendResponse()
        -sendNack()
        -SetCommand()
    }

    class BabelFish {
        +begin()
        +process(char, command)
    }

    class BabelFishCommand_t {
        +cmd
        +data
        +length
        +crc
        +valid
    }

    class UART_CommandStatus_t {
        <<enumeration>>
        VALID
        CMD_INVALID
        DATA_INVALID
        CRC_INVALID
    }

    class CommandBuffer_t {
        +command
        +status
        +type
        +response
    }

    class MotorJob_t {
        +cmd
        +data
        +valid
    }

    class Motor {
        +setJob(MotorJob_t)
        +update()
    }

    UART --> BabelFish : process input characters
    BabelFish --> BabelFishCommand_t : fills command
    UART --> CommandBuffer_t : owns lifecycle
    CommandBuffer_t --> UART_CommandStatus_t : status
    UART --> MotorJob_t : creates job
    MotorJob_t --> Motor : submitted via setJob()
```

## Responsibility boundary

```mermaid
flowchart LR
    S["Serial"] --> U["UART::receive()"]
    U --> B["BabelFish::process()"]
    B --> U
    U --> V["validateCommand()"]
    V --> D["decodeCommand()"]
    D --> M["Motor::setJob()"]
    M --> D
    D --> R["UART response"]
    R --> S
```

### Architectural rule

- **UART** owns Serial reception, command lifecycle, validation, dispatch and response transmission.
- **BabelFish** converts the human-readable ASCII command into the existing binary command structure and handles character echo.
- **Motor** accepts a validated MotorJob_t and owns motor-specific execution.
- There is no separate intermediate command class.

The UART handlers stay thin. Motor-specific execution logic does not move into UART.

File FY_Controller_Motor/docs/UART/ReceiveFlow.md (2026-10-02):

# UART – Receive Flow

The UART receive path has one clear responsibility:

> Receive one ASCII command, let BabelFish convert it into the binary command representation, validate it, and hand it to the existing UART command lifecycle.

UART remains the owner of the receive path and of the command mailbox. BabelFish does **not** own the Serial interface.

## 1. Information flow

```mermaid
flowchart LR
    RX["Serial RX<br/>ASCII"] --> R["UART::receive()"]
    R --> B["BabelFish::process(char)"]

    B -->|NONE| R
    B -->|COMMAND_READY| CB["CommandBuffer.command"]
    B -->|INVALID| CI["CommandBuffer.status<br/>CMD_INVALID"]

    CB --> V["validateCommand()"]
    V -->|valid| READY["commandReady = true"]
    V -->|invalid length| DI["CommandBuffer.status<br/>DATA_INVALID"]
    DI --> READY

    CI --> READY

    READY --> U["UART::update()"]
    U -->|invalid status| N["NACK / response"]
    U -->|valid command| D["decodeCommand()"]
    D --> RESP["sendResponse()"]

    N --> FREE["UART free"]
    RESP --> FREE
    FREE --> R
```

This diagram describes the current productive architecture. There is no additional intermediate command class or duplicate completed-command buffer.

## 2. Character-level receive flow

```mermaid
flowchart TD
    A["Serial.available()"] --> B["Read one character"]
    B --> C["BabelFish::process(c, command)"]

    C -->|NONE| D["Continue receiving"]
    D --> A

    C -->|COMMAND_READY| E["Command complete"]
    E --> F["validateCommand()"]
    F -->|valid| G["status = VALID"]
    F -->|invalid| H["status = DATA_INVALID"]
    G --> I["commandReady = true"]
    H --> I

    C -->|INVALID| J["status = CMD_INVALID"]
    J --> I

    I --> K["UART::update() processes command"]
```

Echo of ordinary ASCII input is handled by BabelFish while processing the character. Echo does not require a second command buffer.

## 3. Command lifecycle

```mermaid
stateDiagram-v2
    [*] --> Receive
    Receive --> Ready: complete command
    Receive --> Ready: invalid command
    Ready --> Processing
    Processing --> Receive: response sent / state cleared
```

commandReady is the UART-level lock.

While commandReady is true, receive() accepts no further command. This prevents a second command from overwriting the command currently being processed.

The lock is released after the response path has completed. An invalid command therefore cannot permanently block UART reception.

## 4. Invalid-command path

```mermaid
flowchart LR
    A["ASCII input"] --> B["BabelFish"]
    B --> C["INVALID"]
    C --> D["CMD_INVALID"]
    D --> E["NACK"]
    E --> F["commandReady = false"]
    F --> G["UART ready for next command"]
```

This behaviour was verified with:

```text
huhu
CMD_INVALID
<binary NACK>
status
CMD=0x19 LEN=1 CRC=0x19
<binary status response>
```

## 5. Responsibility boundary

| Responsibility | Module |
|---|---|
| Read Serial characters | UART |
| Echo input | BabelFish |
| ASCII → binary command | BabelFish |
| Command validation | UART |
| Command mailbox / lifecycle | UART |
| Command dispatch | UART |
| Motor job creation | UART |
| Motor job acceptance / execution | Motor |
| Response transmission | UART |

### Architectural rule

The receive path stays deliberately small:

**UART owns transport and lifecycle. BabelFish translates. UART validates and dispatches. Motor owns motor behaviour.**

No additional intermediate command layer is required.

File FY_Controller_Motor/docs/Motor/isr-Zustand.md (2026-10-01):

# ISR-Zustand – Motor

## Zweck

Dieses Dokument beschreibt den aktuellen Zustand von Timer1, `stepRun`, `profileRun` und dem Referenzlauf in `FY_HW_TEST`.

Es dient als Grundlage für die weitere Untersuchung des Motor- und Positionierverhaltens.

## Grundprinzip

Timer1 erzeugt aktuell dauerhaft Compare-Interrupts. Ob tatsächlich STEP-Pulse erzeugt werden, entscheidet `stepRun`.

```mermaid
flowchart LR
    TIMER["Timer1 Compare ISR"]
    CHECK{"stepRun?"}
    IDLE["STEP LOW<br/>return"]
    STEP["STEP toggeln<br/>Position bearbeiten<br/>Profil bearbeiten"]

    TIMER --> CHECK
    CHECK -->|false| IDLE
    CHECK -->|true| STEP
    STEP --> TIMER
```

Damit ist `stepRun=false` **nicht gleichbedeutend mit einem vollständig beendeten Auftrag**.

## Zustandsfluss

```mermaid
flowchart TD

    START["Start / Setup"]
    TIMER["Timer1 Compare ISR<br/>OCIE1A aktiv"]

    IDLE["Ruhezustand<br/>stepRun = false<br/>profileRun = false"]

    MOVE["Position Move<br/>profileRun = true<br/>stepRun = true"]
    PROFILE["Motorprofil läuft<br/>ACC / V / Position"]
    MOVE_DONE["Profil beendet<br/>profileRun = false<br/>stepRun = false"]
    MOVE_LIMIT["Endschalter<br/>profileRun = false<br/>stepRun = false"]

    REF_START["REF_START<br/>stepRun = true"]
    REF_LEFT["REF_LEFT_END"]
    REF_RIGHT["REF_SEARCH_RIGHT"]
    REF_APPROACH["REF_APPROACH_REF"]
    REF_RETURN["REF_RETURN_TO_REF"]
    REF_SHIFT["REF_SHIFT_LEFT"]
    REF_MEASURE["REF_MEASURE_LEFT"]
    REF_CALC["REF_CALCULATE"]
    REF_VALID["Referenz gültig<br/>refRunActive = false"]
    REF_ERROR["REF_ERROR<br/>refRunActive = false"]

    START --> TIMER
    TIMER --> IDLE

    IDLE -->|Position Move| MOVE
    MOVE --> PROFILE
    PROFILE -->|Profil vollständig abgearbeitet| MOVE_DONE
    PROFILE -->|Endschalter| MOVE_LIMIT
    MOVE_DONE --> IDLE
    MOVE_LIMIT --> IDLE

    IDLE -->|Referenzlauf| REF_START
    REF_START --> REF_LEFT
    REF_LEFT -->|Limit Left| REF_RIGHT
    REF_RIGHT -->|Limit Right| REF_APPROACH
    REF_APPROACH -->|Position erreicht| REF_RETURN
    REF_RETURN -->|Referenzkante erkannt| REF_SHIFT
    REF_SHIFT -->|Position erreicht| REF_MEASURE
    REF_MEASURE -->|2. Messung fertig| REF_CALC
    REF_CALC --> REF_VALID
    REF_VALID --> IDLE

    REF_LEFT -->|Short Reference| MOVE
    REF_LEFT -->|Fehler| REF_ERROR
    REF_ERROR --> IDLE
```

## Timer-Zustand und Bewegungszustand

Für die weitere Architektur sollten zwei Dinge getrennt betrachtet werden:

```mermaid
stateDiagram-v2

    [*] --> TIMER_OFF

    TIMER_OFF --> TIMER_ON: Bewegung / Referenzphase starten

    state TIMER_ON {

        [*] --> PAUSE

        PAUSE --> RUN: stepRun = true
        RUN --> PAUSE: stepRun = false

        RUN --> RUN: Timer ISR erzeugt STEP
    }

    TIMER_ON --> TIMER_OFF: kompletter Auftrag beendet
```

### Bedeutung

| Zustand | Bedeutung |
|---|---|
| Timer OFF | Timer1 Compare-Interrupt deaktiviert |
| Timer ON + `stepRun=false` | ISR läuft, erzeugt aber keine Schritte |
| Timer ON + `stepRun=true` | Motor kann Schritte erzeugen |
| Timer OFF nach Auftrag | kompletter Bewegungs-/Referenzauftrag beendet |

## Wichtige Beobachtung

Der aktuelle Code aktiviert in `init_step_timer()` dauerhaft:

```cpp
TIMSK1 |= _BV(OCIE1A);
```

Die ISR selbst verhindert bei `stepRun=false` weitere STEP-Flanken:

```cpp
if (!stepRun)
{
    stepLevel = false;
    PORTD &= ~_BV(PD3);
    return;
}
```

Bei einem normalen Positionierprofil wird am Ende außerdem:

```cpp
profileRun = false;
stepRun = false;
```

gesetzt.

**Daraus folgt:** Der dauerhaft aktivierte Timer ist nach aktuellem Codeverständnis nicht automatisch die Ursache für weitere Motor-Schritte. Er läuft jedoch unnötig weiter und ist vom eigentlichen Bewegungszustand getrennt.

## Konsequenz für die weitere Untersuchung

Der Timer-Interrupt sollte nicht einfach bei jedem

```cpp
stepRun = false;
```

deaktiviert werden.

Im Referenzlauf wird `stepRun=false` mehrfach nur als kurze Pause zwischen zwei Bewegungsphasen verwendet.

Sinnvoll wäre daher eine spätere Trennung von:

- **Timer1 aktiv/inaktiv**
- **`stepRun`**
- **`profileRun`**
- **`refRunActive` / `refRunState`**

Erst danach sollte entschieden werden, an welchen terminalen Zuständen der Timer tatsächlich abgeschaltet wird.

## Aktueller Stand

- Keine Änderung am Motorcode durch dieses Dokument.
- Diagramm beschreibt den aktuellen Stand und die daraus abgeleitete Zielstruktur.
- Die Frage nach einem möglichen ungewollten Weiterlaufen des Motors bleibt ein eigener Prüfschritt.

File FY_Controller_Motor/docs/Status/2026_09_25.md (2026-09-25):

# FY UVB – Projektstatus

**Stand: 25.09.2026**

## 1. Kurzfassung

Seit dem letzten Projektstatus vom **22.09.2026** ist das Projekt deutlich weiter.

Der wichtigste Fortschritt dieser Woche ist der Übergang von der reinen Softwarearchitektur zur **realen Hardware-Inbetriebnahme**.

Besonders weit ist inzwischen der separate **FY_HW_Test**:

- PCF8574 und Tastereingänge funktionieren.
- LED-/Taster-Zuordnung ist praktisch geprüft.
- OLED zeigt die relevanten Zustände.
- Die drei Lichtschranken/Endsensoren sind mechanisch montiert und werden vom Controller sauber erkannt.
- Die Referenzfahnen lösen die Sensoren an den vorgesehenen Positionen aus.
- Ein einfacher Timer1-basierter STEP-Generator ist vorhanden.
- ENABLE, DIR und STEP können ohne produktive Motorlogik separat getestet werden.
- Die Endschalter können den Testmotor bereits unmittelbar in der jeweils gesperrten Richtung stoppen.
- Die STEP-Testfrequenz kann inzwischen ausgewählt bzw. verändert werden.

Damit ist **#84 – FY_HW_Test** inzwischen der praktische Inbetriebnahme-Knotenpunkt.

Die produktive Motorsoftware ist dagegen bewusst noch nicht mit diesem Hardwaretest vermischt. Dort liegen die nächsten Schritte weiterhin bei prepare-Funktionen, Motorzustand, State Machine, produktiver Timer1-ISR und Positionsführung.

> **Die Hardwareseite ist inzwischen weit genug, dass der nächste sinnvolle Schritt ein echter Motor-Hardwaretest ist. Die Produktivsoftware muss dafür nicht vorgezogen oder künstlich vereinfacht werden.**

---

# 2. Status nach Bereichen

| Bereich | Status | Aktueller Stand |
|---|---|---|
| Hardware-Smoke-Test #84 | 🟢/🟡 | sehr weit, letzte physische Motorprüfung offen |
| Lichtschranken / Endsensoren | 🟢 | montiert, Fahnen montiert, Auslösung praktisch bestätigt |
| Taster / PCF8574 | 🟢 | Eingänge und Zuordnung geprüft |
| OLED / lokale Diagnose | 🟢 | Hardwaretest zeigt Zustände |
| Motor-Hardwarepfad | 🟡 | ENABLE/DIR/STEP-Testsoftware vorhanden; reale Motorfahrt als nächster Schritt |
| Riemenantrieb | 🟡 | mechanische Kopplung noch bewusst zurückgestellt |
| 12-V-Verdrahtung | 🟡 | für Motor-Inbetriebnahme noch fertigzustellen |
| Motor-Grundstruktur | 🟡 | vorhanden, produktiver Ablauf noch nicht fertig |
| calcProfile #23 | 🟢 | implementiert |
| prepare... #24 | 🟡 | spezifiziert, Code noch Stub |
| Motor Enable/Disable #86 | 🟡 | fachlich definiert, produktiv noch nicht implementiert |
| State Machine #50 | 🔴 | Gerüst vorhanden, zentraler Ablauf noch offen |
| Timer1/STEP produktiv #51 | 🔴 | Architektur vorhanden, ISR noch nicht fertig |
| Positionierung #49/#52 | 🔴 | noch nicht ausführbar |
| Referenzfahrt #27 | 🔴 | fachlich detailliert, Implementierung offen |
| Referenzkorrektur #85 | 🟡 | Konzept definiert |
| UART Empfang | 🟡/🟢 | wesentliche Basis vorhanden |
| UART → Motor #28 | 🟡 | Schnittstelle vorhanden, produktiver Ablauf noch nicht fertig |
| UART BUSY #29 | 🟡 | offen |
| main.cpp Integration #30 | 🟡 | noch nicht vollständig |
| UART CRC #18 | 🟢 | abgeschlossen |
| UART Robustheit #17 | 🟡 | noch offen |
| Tests #46, #60–#71 | 🔴/🟡 | Teststruktur vorhanden, Implementierung noch weitgehend offen |
| Dokumentation | 🟢 | deutlich gewachsen, Mermaid-Dokumentation vorhanden |

---

# 3. Der große Fortschritt: Hardware-Smoke-Test #84

Der Hardwaretest hat sich seit dem letzten Status stark entwickelt.

## 3.1 I²C / PCF8574

Die PCF8574-Anbindung wurde stabilisiert.

Vorhanden bzw. praktisch geprüft:

- Taster P4–P7
- LED-Ausgänge
- OLED über I²C
- I²C-Adresserkennung
- Eingangs-Pull-up-Verhalten
- zentrale IO-Verarbeitung

Die frühere Mapping-Testlogik wurde bewusst vereinfacht. Der Test ist damit nicht mehr primär ein Zuordnungsprogramm, sondern zunehmend ein **echter Hardware-Smoke-Test**.

## 3.2 Lichtschranken

Hier ist inzwischen ein wesentlicher realer Meilenstein erreicht.

Physisch vorhanden:

    LINKS                                      RECHTS

    [LS_LEFT] ---- [REF-Fahne / LS_REF] ---- [LS_RIGHT]

Die Fahnen auf der Bühne lösen die Lichtschranken an den vorgesehenen Stellen aus.

Der Controller liest die Eingänge sauber ein.

Damit ist die grundlegende Sensorhardware für:

- linke Grenze
- rechte Grenze
- Referenzposition

praktisch nachgewiesen.

Der spätere BELT_SENSOR bleibt separat; dafür muss nach einem beschädigten Kabel noch ein neues Servokabel beschafft werden.

---

# 4. Hardware-Test: STEP / DIR / ENABLE

Der wichtigste neue Softwarebaustein des Smoke-Tests ist inzwischen vorhanden:

    Taster
      ↓
    HW-Test
      ↓
    ENABLE
    DIR
    STEP
      ↓
    Timer1

Der Hardwaretest erzeugt eine einfache konstante STEP-Frequenz.

Er verwendet bewusst:

- keinen MotorJob
- kein prepare()
- kein Bewegungsprofil
- keine produktive Positionslogik
- keine produktive Motor-State-Machine

Damit kann die reale Hardware getestet werden, ohne gleichzeitig die Produktivsoftware debuggen zu müssen.

---

# 5. Endschalter-Sicherheit im Hardwaretest

Der Smoke-Test enthält inzwischen zusätzlich eine direkte Sicherheitsbegrenzung im Timer1-Interrupt.

Prinzip:

    STEP-Test läuft
          ↓
    Fahrtrichtung prüfen
          ↓
    passender Endschalter aktiv?
       ├── JA → STEP sofort stoppen
       └── NEIN → STEP weiter erzeugen

Die Gegenrichtung bleibt möglich.

Das ist ausdrücklich **nur Hardwaretest-Sicherheit**.

Es ersetzt nicht die spätere produktive Motor-/Referenzlogik aus #51, #27 und #81.

---

# 6. STEP-Testfrequenz

Der Hardwaretest wurde inzwischen mehrfach weiterentwickelt:

- feste einfache STEP-Erzeugung
- Umrechnung über Timer1
- auswählbare STEP-Frequenzen
- verbesserte Berechnung des Timer-Reload-Wertes
- Anzeige des aktuellen Testzustands

Damit können wir die Reaktion von Treiber, Motor und später Mechanik getrennt von der Profilsteuerung untersuchen.

Für die erste reale Motorfahrt ist weiterhin bewusst eine **langsame Geschwindigkeit** vorgesehen.

---

# 7. Was noch zur Hardware-Inbetriebnahme fehlt

Die Softwareseite des Smoke-Tests ist inzwischen weit.

Physisch fehlen vor der ersten vollständigen Motorfahrt noch:

1. 12-V-Verdrahtung unter dem Modul fertigstellen.
2. Motor zunächst **ohne Riemen/Bühne** anschließen.
3. ENABLE / DIR / STEP bei langsamer Testgeschwindigkeit prüfen.
4. Motorverhalten beobachten.
5. Erst danach den Riemen auflegen.
6. Anschließend Bühne mechanisch bewegen.
7. Endschalter unter realer Bewegung prüfen.

Diese Reihenfolge ist bewusst gewählt:

    Controller
       ↓
    Treiber
       ↓
    Motor allein
       ↓
    Riemen
       ↓
    Bühne

Damit wird nicht gleichzeitig ein unbekannter Motor-/Treiberfehler mit einer mechanischen Ursache vermischt.

---

# 8. Produktive Motorsoftware

Hier hat sich gegenüber dem letzten Status vor allem die fachliche Definition verbessert.

## calcProfile #23

**🟢 abgeschlossen**

Das Profil wird vollständig vor der ISR berechnet.

Die sechs Bereiche sind:

    ACC1 → ACC2 → KONST → BRE1 → BRE2 → POSI

Die vereinbarten Eigenschaften sind festgelegt.

Die Mathematik gehört nicht in die ISR.

---

# 9. prepare... #24

**🟡 als nächster produktiver Motorblock**

Die gemeinsame Struktur ist inzwischen eindeutig:

    Bewegungsauftrag
          ↓
    Motor ON?
          ↓
    Job
          ↓
    Ziel bestimmen
          ↓
    Ziel plausibilisieren
          ↓
    Referenz prüfen
          ↓
    Grenzen prüfen
          ↓
    TargetPosition
          ↓
    calcProfile()
          ↓
    TimerValid

Wichtig ist die neue Entscheidung:

> **Motor ON/OFF wird logisch separat von der Referenzgültigkeit geführt und ist die erste Prüfung jeder prepare-Funktion.**

Damit kann niemals ein gültiges Bewegungsprofil vorbereitet werden, obwohl der Motor elektrisch deaktiviert ist.

Die Mermaid-Dokumentation für PrepareLeft und PrepareRight wurde entsprechend angepasst und mit #86 verknüpft.

---

# 10. Motor Enable / Disable #86

**🟡 fachlich definiert, noch nicht produktiv umgesetzt**

Geplant sind zwei unabhängige logische Zustände:

    motorEnabled
    referenceValid

Dabei gilt:

    Motor ON + Referenz gültig
        → normale Bewegung

    Motor ON + Referenz ungültig
        → nur erlaubte Initialisierung / Referenzierung

    Motor OFF
        → keine normale Bewegung
        → Referenz wird ungültig

Motor ON aktiviert nur den Motor.

Motor OFF:

- stoppt STEP
- deaktiviert ENABLE
- verwirft den laufenden Auftrag
- macht die Position ungültig
- setzt die Referenz ungültig

Das ist für die produktive Motorlogik wichtig, aber bewusst noch nicht in den Hardware-Smoke-Test hineingezogen.

---

# 11. Produktiver Timer1 / ISR #51

**🔴 noch offen**

Die produktive ISR soll wesentlich mehr leisten als der Smoke-Test:

    MotorProfile
          ↓
    Timer1
          ↓
    STEP
          ↓
    Position +/- 1
          ↓
    Segmentwechsel
          ↓
    Profilende / Endschalter

Bereits festgelegt:

- logische Richtung im Profil
- physische DIR-Ausgabe erst bei tatsächlicher Bewegung
- direkte Registerzugriffe im zeitkritischen Pfad
- keine digitalWrite-Aufrufe im STEP-Pfad
- keine Profilberechnung in der ISR
- keine UART-Kommunikation in der ISR
- Endschalter als physisches Ereignis
- fachliche Fehlerbewertung außerhalb der ISR

Die Hardware-Testsoftware ist dabei ein **Vorläufer zum Nachweis der Hardware**, nicht die produktive Implementierung.

---

# 12. State Machine #50

**🔴 offen**

Im Produktivcode existiert das Gerüst:

    IDLE
    CONF
    REFRUN
    MOVING
    STOPPED
    ERROR

Die eigentliche Orchestrierung ist aber noch nicht fertig.

Der nächste sinnvolle Aufbau bleibt:

    Job
     ↓
    prepare
     ↓
    MOVING
     ↓
    Timer/ISR
     ↓
    Bewegung beendet
     ↓
    Folgezustand

---

# 13. Referenzfahrt #27

**🔴 fachlich weit, technisch noch offen**

Die Sensorhardware ist jetzt deutlich weiter als beim letzten Status.

Damit können wir die bisherige Referenzdefinition jetzt auf reale Hardware beziehen:

    LS_LEFT
       ↓
    Referenzfahne / LS_REF
       ↓
    LS_RIGHT

Die geplante Referenzfahrt bleibt:

    START
     ↓
    END_L prüfen
     ↓
    ggf. freifahren
     ↓
    langsam nach links
     ↓
    END_L
     ↓
    nach rechts
     ↓
    Referenzfahne suchen
     ↓
    END_R
     ↓
    Messwerte auswerten
     ↓
    REF_VALID / REF_ERROR

Noch offen sind insbesondere die Implementierung der State Machine und die tatsächliche Positionszählung.

---

# 14. Referenzkorrektur #85

**🟡 spezifiziert**

Die Korrektur bleibt bewusst einfach:

    Δ = Ist - Soll

    |Δ| <= TOL
        → nichts

    TOL < |Δ| <= MAX_CORRECTION
        → Softwarekorrektur

    |Δ| > MAX_CORRECTION
        → REF_ERROR

Das ist eine kleine Robustheitsfunktion und kein Regelkreis.

---

# 15. UART

Die UART-Basis ist weiterhin brauchbar.

Vorhanden bzw. implementiert:

- 115200 Baud
- Command-Erkennung
- feste Telegrammlängen
- Receive-State-Machine
- Timeout-Verhalten
- CRC-Berechnung
- optionaler RX-CRC
- CommandBuffer
- Response-Struktur
- UART → MotorJob_t
- Motor.setJob() als definierte Schnittstelle

## CRC #18

**🟢 abgeschlossen**

## Robustheit #17

**🟡 offen**

Die noch offene Rückmeldung und Fehlerbehandlung bleibt relevant, ist aber für den allerersten nackten Motor-Hardwaretest nicht erforderlich.

---

# 16. UART ↔ Motor / Systemintegration

Die Issues #28, #29 und #30 sind weiterhin offen.

Der aktuelle Produktivcode zeigt:

    UART
     ↓
    MotorJob
     ↓
    Motor.setJob()

als vorgesehene Architektur.

Die vollständige Laufzeitintegration ist aber noch nicht hergestellt.

Insbesondere muss main.cpp später wieder einen gemeinsamen Zyklus ausführen, beispielsweise:

    UART.update()
    Motor.Update()
    Keyboard.update()
    Switches.update()
    System...

Die endgültige Reihenfolge wird erst mit der tatsächlichen Integration festgelegt.

---

# 17. Tests

Die Teststruktur ist inzwischen wesentlich umfangreicher als die tatsächlich implementierten Tests.

## Bereits real

### calcProfile()

Das ist weiterhin der sauberste hardwareunabhängige Produktivtest.

## Hardware-Smoke-Test

#84 ist inzwischen ein echter praktischer Hardwaretest und nicht nur ein Software-Sanity-Check.

## Noch offen

Die Issues #60–#71 beschreiben Tests für:

    Motor begin
    setJob
    move2Pos / moveSteps
    State Machine
    Timer1 / STEP
    Status / Position
    UART Receive
    UART → Motor
    Motor → UART
    ACK / BUSY / DONE
    main.cpp Integration
    Telegrammdefinitionen

Diese bleiben bewusst nachgelagert.

---

# 18. Architektur: Zwei Testwelten bleiben getrennt

Wir haben jetzt eine sinnvolle Trennung:

                  FY UVB
                    │
          ┌─────────┴─────────┐
          │                   │
     Produktivsoftware    FY_HW_Test
          │                   │
     Motor / UART /       reale Hardware
     System / Profile     direkt prüfen
          │                   │
          └─────────┬─────────┘
                    │
                 Hardware

Der Hardware-Smoke-Test darf dabei sehr primitiv sein.

Das ist kein zweites Produkt und keine Parallelarchitektur.

Er ist unser **Inbetriebnahmewerkzeug**.

---

# 19. Speicher / Nano

Der Hardwaretest bestätigt außerdem eine wichtige Architekturannahme:

Wir brauchen auf dem Nano keine umfangreiche lokale Bedienoberfläche.

Die lokale Bedienung bleibt bewusst klein:

    ROT    → STOP
    GRÜN   → REFERENCE / später MOTOR ON
    BLAU   → Bewegung
    BLAU   → Bewegung

Das OLED muss keine komplette Diagnoseoberfläche werden.

Für Fehler reicht beispielsweise:

    ERROR: 23

Detaillierte Fehlertexte und komfortable Diagnose können später auf dem ESP32 liegen.

Damit ist momentan kein Controllerwechsel aufgrund des Speichers erforderlich.

---

# 20. Aktueller Engpass

Der Projektengpass hat sich gegenüber dem Status vom 22.09. verschoben.

Damals war es im Wesentlichen:

    Motorarchitektur

Heute ist es:

    Hardware
       ↓
    Motor allein zum Laufen bringen

und parallel:

    Produktivmotor
       ↓
    prepare...
       ↓
    State Machine
       ↓
    Timer1 / ISR
       ↓
    Positionszählung

Das sind jetzt zwei klar getrennte Arbeitsstränge.

---

# 21. Sinnvolle nächste Reihenfolge

## A – Hardware

    12-V-Verdrahtung
          ↓
    Motor + Treiber
          ↓
    HW-Test
          ↓
    langsames STEP
          ↓
    Richtung / STOP / ENABLE
          ↓
    Motor ohne Bühne

Danach:

    Riemen
     ↓
    Bühne
     ↓
    reale langsame Fahrt
     ↓
    Endschalter

## B – Produktivsoftware

Parallel bzw. danach:

    #24 prepare...
          ↓
    #86 Motor ON/OFF
          ↓
    #50 State Machine
          ↓
    #51 produktiver Timer1/ISR
          ↓
    #52 Position
          ↓
    #27 Reference

UART- und Systemintegration folgt anschließend.

---

# 22. Was ausdrücklich noch NICHT nötig ist

Für die nächste reale Bewegung brauchen wir nicht:

- umfangreiche Menüführung
- komplexe Fehlerdiagnose
- ESP32
- Webinterface
- Bewegungsanimation
- Step-Servicebetrieb
- vollständige POR-Logik
- umfangreiche UART-Diagnose
- perfekte Fehlerhistorie

Der Nano muss zunächst nur das tun, was für die Bewegung notwendig ist.

---

# 23. Gesamtbild

mermaid:
flowchart LR
    HW["Reale Hardware<br/>🟢 Sensoren<br/>🟡 Motor"]
    HWT["FY_HW_Test<br/>🟢 sehr weit"]
    PREP["prepare...<br/>🟡 spezifiziert"]
    PROF["calcProfile<br/>🟢"]
    STATE["Motor State Machine<br/>🔴"]
    TIMER["Produktiver Timer1 / ISR<br/>🔴"]
    POS["Position<br/>🔴"]
    REF["Reference<br/>🔴"]
    UART["UART<br/>🟡"]
    SYS["System Integration<br/>🔴"]

    HW --> HWT
    HWT -.-> PREP
    UART --> PREP
    PREP --> PROF
    PROF --> STATE
    STATE --> TIMER
    TIMER --> POS
    POS --> REF
    REF --> SYS
    STATE --> SYS
    UART --> SYS

---

# 24. Fazit

Seit dem letzten Status ist ein wichtiger Schritt gelungen:

> **Wir sind nicht mehr nur dabei, einen Motorcontroller zu entwerfen. Wir haben inzwischen eine reale, geprüfte Hardwarebasis, auf der wir ihn in Betrieb nehmen können.**

Die Lichtschranken und Fahnen sind mechanisch an ihrem vorgesehenen Platz und werden vom Controller sauber erkannt.

Der Hardware-Smoke-Test hat inzwischen einen eigenen Timer1-STEP-Generator, ENABLE/DIR-Steuerung, Endschalter-Sperre und auswählbare Testfrequenzen.

Damit ist der nächste Hardware-Meilenstein sehr konkret:

**Motor ohne Riemen langsam drehen lassen.**

Parallel bleibt die Produktivsoftware sauber getrennt. Dort ist calcProfile fertig; der nächste echte Block sind die prepare-Funktionen mit dem inzwischen festgelegten **Motor-ON-Check an erster Stelle**.

Die Architektur ist damit momentan nicht der Engpass.

**Jetzt darf endlich ein Motor Geräusche machen.**

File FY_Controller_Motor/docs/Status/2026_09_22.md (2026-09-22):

# FY UVB – Projektstatus

**Stand: 22.09.2026**

## 1. Kurzfassung

Das Projekt hat inzwischen eine recht klare Grundarchitektur:

* **Motor** – Kern der Bewegungssteuerung
* **UART** – Remote-Kommunikation
* **Keyboard** – lokale Bedienung + OLED
* **Switches** – Rohzugriff auf Sensoren
* **System** – übergreifender Zustand und Integration
* **Reference** – fachlich definiert, technisch aber noch nicht umgesetzt
* **Tests** – vorhanden, aber bisher hauptsächlich für die Profilberechnung
* **Dokumentation** – erste Mermaid-Diagramme und Systemdokumente vorhanden

Der auffälligste Punkt ist:

> **Die einzelnen Module sind weiter entwickelt als ihre Integration.**

Das ist für den jetzigen Projektstand sogar sinnvoll. Wir haben damit bereits Bausteine, die man einzeln bearbeiten kann.

---

# 2. Status nach Modul

| Bereich |  Issue beschrieben | Code vorhanden | Integrationsstand |
| --- | ---: | ---: | ---: |
| Motor-Grundstruktur | ✓ | ✓ | 🟡 |
| Fahrprofil | ✓ | ✓ | 🟢 |
| Motor `setJob()` | ✓ | ✓ | 🟡 |
| Motor State Machine | ✓ | teilweise | 🔴 |
| Timer1 / STEP / ISR | ✓ | vorbereitet, aber nicht fertig | 🔴 |
| Positionierung | ✓ | überwiegend Stub | 🔴 |
| Referenzfahrt | ✓ | State vorhanden, Logik fehlt | 🔴 |
| Motor Enable / Reference validity | ✓ | Konzept vorhanden | 🔴 |
| UART Empfang | ✓ | ✓ | 🟡 |
| UART CRC | ✓ | vorhanden, RX optional | 🟡 |
| UART → Motor | ✓ | teilweise | 🟡 |
| UART ACK/BUSY/DONE | ✓ | noch nicht fertig | 🔴 |
| Keyboard Architektur | ✓ | ✓ | 🟢 |
| Taster | ✓ | ✓ | 🟢 |
| OLED | ✓ | ✓ | 🟢 |
| LOCAL/REMOTE | ✓ | Zustand vorhanden | 🟡 |
| Keyboard → Motor/System | ✓ | noch nicht | 🔴 |
| Switches Rohklasse | ✓ | ✓ | 🟡 |
| Switches → Motor ISR | fachlich notwendig | noch offen | 🔴 |
| POR / Startablauf | ✓ | noch nicht | 🔴 |
| Step-Servicebetrieb | ✓ | noch nicht | ⚪ |
| Systemintegration | ✓ | teilweise | 🔴 |
| Unit-/Modultests | ✓ | teilweise | 🔴 |
| Dokumentation | ✓ | teilweise | 🟡 |

---

# 3. Was tatsächlich schon im Code steckt

## 🟢 Keyboard

Das ist inzwischen erstaunlich weit.

Vorhanden:

* 4 Taster
* PCF8574-Anbindung
* Zuordnung der Taster
* 50-ms-Entprellung
* Flankenerkennung
* STOP mit Priorität
* OLED 128×64
* Page-Buffer
* LOCAL/REMOTE
* TRACK-Anzeige
* READY/MOVING
* ERROR/E##
* I²C-Erkennung
* `is_connected()`
* Diagnosefeld für letzten Command vorbereitet

Damit ist das **Keyboard kein Konzept mehr**, sondern ein echter Codebaustein.

Was noch fehlt:

* tatsächliche Verbindung der Events mit der Systemlogik
* POR-Anzeige
* Referenzlauf-Anzeige
* LED-Zustandssteuerung als Teil des Ablaufs
* LOCAL/REMOTE tatsächlich systemweit schalten
* Diagnoseanzeige

---

# 4. 🟡 Switches

Die Rohklasse existiert.

Sie kann:

```text
REF
TRIM_LEFT
TRIM_RIGHT
TIMING_BELT
```

adressieren und digitale Rohwerte lesen.

Analog ist bereits berücksichtigt:

```text
kein Analogkanal → 0xFF
```

Das ist genau die richtige Größenordnung für diesen Schritt.

Aber:

> Die Switches wissen momentan noch nicht, **was ein Referenzsensor oder Endschalter bedeutet**.

Das ist gut.

Die Interpretation gehört in die Referenz-/Motorlogik.

---

# 5. 🟢 Motor – was schon real ist

Der Motor hat bereits eine brauchbare Grundstruktur.

Vorhanden:

```text
Motor
 ├── begin()
 ├── setJob()
 ├── Update()
 ├── Stop()
 ├── Emergency_break()
 ├── Reference()
 ├── move2Pos()
 ├── moveSteps()
 ├── calcProfile()
 └── Status-/Positionszugriff
```

### Besonders wichtig

`calcProfile()` ist nicht mehr nur Papier.

Es gibt bereits einen echten Test:

```text
distance
   ↓
ACC1
ACC2
KONST
BRE1
BRE2
POSI
   ↓
Summe == distance
```

und die Symmetrien werden geprüft.

Das ist unser erster echter **grüner Kernbereich**.

---

# 6. 🔴 Motor – was noch fehlt

Hier liegt momentan der größte Block.

Die Methoden existieren teilweise nur als Gerüst:

```text
move2Pos()
moveSteps()
Reference()
prepareLeft()
prepareRight()
prepareSetTrack()
prepareSetPosition()
prepareParameter()
CheckBorder()
```

Die State Machine ist ebenfalls noch nicht ausführbar.

Noch fehlen insbesondere:

### Bewegung

```text
Job
 ↓
prepare
 ↓
calcProfile
 ↓
Timer1
 ↓
STEP
 ↓
Position
 ↓
Target erreicht
 ↓
DONE
```

### Timer1

Der Timer ist vorbereitet, aber der eigentliche vollständige Executor fehlt.

### Position

Die Position muss bei jedem gültigen STEP richtungsabhängig verändert werden.

Und genau hier kommen wir zu deinem aktuellen Gedankenproblem:

> **ISR und Switches dürfen nicht einfach zwei unterschiedliche Hardwarewelten bedienen.**

Das ist tatsächlich ein Architekturpunkt, den wir vor dem nächsten großen Motor-Schritt sauber entscheiden sollten.

---

# 7. 🔴 Referenzfahrt

Die fachliche Beschreibung ist inzwischen ziemlich gut.

Wir wissen:

```text
POR
 ↓
LOCAL
 ↓
Start
 ↓
ENABLE
 ↓
Endlage links
 ↓
Endlage rechts
 ↓
Referenzfahne
 ↓
Messwerte
 ↓
REF_VALID
```

Auch das Koordinatensystem ist grundsätzlich beschrieben.

Aber die eigentliche Referenz-State-Machine fehlt noch.

Das bedeutet:

**Die Spezifikation ist deutlich weiter als die Implementierung.**

Das ist momentan vermutlich die größte Differenz im gesamten Projekt.

---

# 8. 🟡 UART

UART ist ebenfalls deutlich weiter als nur ein Stub.

Vorhanden:

* 115200 Baud
* Empfangs-State-Machine
* Command-Erkennung
* Command-Längen
* CRC-Funktion
* optionaler CRC-RX
* Response Buffer
* `Hello my friend`
* Command Dispatcher
* MotorJob-Erzeugung
* UART → Motor `setJob()`

Das ist schon ein ordentliches Fundament.

Aber:

```text
UART
 ↓
Command
 ↓
Motor
```

ist noch nicht vollständig rückgekoppelt.

Es fehlen insbesondere:

```text
Motor
 ↓
Status
 ↓
UART
 ↓
ACK / BUSY / DONE / ERROR
```

sowie die endgültige Semantik von:

* ACK
* BUSY
* DONE
* ResponsePending
* Fehlerantworten
* Kommunikationsverlust

---

# 9. 🔴 Systemintegration

Hier sitzt momentan der eigentliche Engpass.

`main.cpp` kennt bereits:

```text
UART
Motor
Keyboard
```

und der `FY_ModuleContext` verbindet sie.

Aber der zyklische Ablauf ist noch nicht zusammengebaut.

Aktuell läuft im Wesentlichen:

```text
loop()
  ↓
UART.update()
```

Während Dinge wie

```text
Motor.Update()
Keyboard.update()
Switches...
System-State...
```

noch nicht sauber in einem gemeinsamen Zyklus laufen.

Das erklärt auch, warum wir trotz vieler fertiger Bausteine noch nicht sagen können:

> „Jetzt funktioniert der komplette Controller.“

---

# 10. 🔴 POR

Das neue Issue #94 beschreibt inzwischen einen ziemlich vollständigen Ablauf:

```text
Power On
 ↓
LOCAL
 ↓
Begrüßung
 ↓
5 s
 ↓
"Taster Grün für Start"
 ↓
Grün
 ↓
ENABLE
 ↓
Referenzlauf
 ↓
Rot EIN
 ↓
Referenzschritte anzeigen
 ↓
Ergebnis anzeigen
 ↓
Grün quittiert
 ↓
Step / Track auswählen
```

Das ist jetzt eine **System-Spezifikation**.

Im Code ist davon bisher nur ein Teil der dafür benötigten Komponenten vorhanden.

Das ist genau der richtige nächste Integrationsblock — aber erst nachdem Motor/Referenz technisch fahrfähig sind.

---

# 11. 🔴 Tests

Hier sieht man einen interessanten Unterschied zwischen Issue-Struktur und Realität.

Beschrieben sind Tests für:

* Motor-Grundinitialisierung
* `setJob()`
* Bewegungsaufträge
* State Machine
* Timer1
* Status/Position
* UART
* UART → Motor
* Systemintegration

Tatsächlich gefunden habe ich derzeit als konkreten Motor-Test insbesondere:

```text
test_calcProfile.cpp
```

Der ist sinnvoll und prüft echte Eigenschaften.

Aber der große Rest der Teststruktur ist noch **geplant, nicht umgesetzt**.

Das ist ein wichtiger Punkt für unseren Status:

> **Die Test-Issues sind bereits detaillierter als die vorhandene Testimplementierung.**

---

# 12. Der eigentliche Projektfluss

Und jetzt die etwas wildere Darstellung.

**Legende:**

* 🟢 durchgezogene Linie = im Code bereits verbunden
* 🟡 gestrichelte Linie = fachlich vorgesehen, aber noch nicht vollständig implementiert
* Kästchen mit `~` = teilweise implementiert
* Kästchen mit `?` = noch offen

```mermaid
flowchart LR

    USER["Bediener"]

    KB["Keyboard<br/>✓ Taster + OLED<br/>✓ LOCAL / REMOTE"]
    SW["Switches<br/>✓ Rohzugriff"]
    
    SYS["FY System<br/>~ Status / Context"]
    
    UART["UART<br/>~ Receive / Decode / CRC"]
    
    JOB["MotorJob<br/>✓ Datenstruktur"]
    
    PREP["Prepare<br/>? Position / Track / Limits"]
    
    PROF["Profile<br/>✓ calcProfile"]
    
    TIMER["Timer1 / ISR<br/>? STEP Executor"]
    
    POS["Position<br/>? +/- STEP"]
    
    REF["Reference<br/>? Referenz-State-Machine"]
    
    SENSOR["Sensoren<br/>✓ Rohzugriff<br/>? Interpretation"]
    
    STATUS["Status / Response<br/>? ACK / BUSY / DONE / ERROR"]

    USER --> KB

    KB --> SYS
    SW -.-> REF

    SYS --> UART
    UART --> JOB
    JOB --> PREP
    PREP --> PROF
    PROF -.-> TIMER
    TIMER -.-> POS

    SENSOR -.-> TIMER
    SENSOR -.-> REF

    REF -.-> POS
    REF -.-> SYS

    POS -.-> STATUS
    TIMER -.-> STATUS

    STATUS -.-> UART
    SYS -.-> KB
```

---

# 13. Noch besser: der Weg zu „erste echte Bewegung“

Wenn wir das Diagramm auf den **kleinsten sinnvollen nächsten Meilenstein** reduzieren, sieht es so aus:

```mermaid
flowchart LR

    KB["Keyboard<br/>✓"]
    UART["UART<br/>~"]
    JOB["MotorJob<br/>✓"]
    PREP["prepare...<br/>✗"]
    PROF["calcProfile<br/>✓"]
    TIMER["Timer1 + ISR<br/>✗"]
    STEP["STEP<br/>✗"]
    POS["Position<br/>✗"]

    KB -.-> UART
    UART --> JOB
    JOB -.-> PREP
    PREP --> PROF
    PROF -.-> TIMER
    TIMER -.-> STEP
    STEP -.-> POS
```

Und daraus ergibt sich für mich ziemlich klar:

## Der nächste technische Engpass ist nicht Keyboard.

Auch nicht UART.

Auch nicht noch eine weitere Abstraktion.

**Der nächste Engpass ist:**

```text
MotorJob
   ↓
prepare
   ↓
calcProfile
   ↓
Timer1
   ↓
STEP
   ↓
Positionszähler
```

Und **parallel dazu müssen wir die ISR ↔ Switches-Frage klären**, bevor wir die Endschalter dort hineinhängen.

---

# 14. Was uns auf Projektebene noch fehlt

Ich würde momentan sieben große offene Blöcke sehen:

### ① Motor wirklich fahren lassen 🔴

`prepare → profile → Timer1 → STEP`

### ② Positionszählung 🔴

Richtung + STEP → `_Position`

### ③ Sensorzugriff für ISR/Endschalter 🔴

Hier genau deine aktuelle Architekturfrage.

### ④ Referenzfahrt 🔴

Die inzwischen sehr gut beschriebene State Machine muss implementiert werden.

### ⑤ Systemzyklus 🔴

```text
Keyboard
UART
Motor
Switches
System
```

müssen tatsächlich gemeinsam laufen.

### ⑥ Rückmeldung 🔴

```text
Motor/System
 ↓
Status
 ↓
UART
 ↓
Remote
```

### ⑦ Teststrecke 🟡 → 🔴

Erst Modultests, dann:

```text
Motor
 ↓
Hardware
 ↓
erste Bewegung
 ↓
Referenz
 ↓
Track
 ↓
STOP / Emergency
 ↓
POR
```

---

# 15. Und was ich ausdrücklich NICHT als „noch fehlt“ zählen würde

Ein paar Dinge sehen in den Issues größer aus, als sie für den nächsten Schritt tatsächlich sind:

* Step-Servicebetrieb #95 → **später**
* Bewegungsanimation → **später**
* Diagnosebildschirm → **später**
* perfekte Dokumentation → **später**
* CRC-Feinschliff → wichtig, aber nicht vor der ersten Bewegung
* BELT_SENSOR → später
* umfangreiche Menülogik → brauchen wir wahrscheinlich überhaupt nicht
* weitere Abstraktionsschichten → bitte nicht 😁

---

# 16. Der innere Monk bekommt damit ein ziemlich klares Bild

Wir haben derzeit ungefähr:

```text
             SPEZIFIKATION
                  ███████████████████
                  █████████████████
                  ███████████████

             CODE-BASIS
                  ███████████████
                  █████████████
                  ███████████

             INTEGRATION
                  ███████
                  █████
                  ███

             HARDWARE-LAUF
                  ███
                  ██
                  █
```

Das bedeutet nicht, dass wir „hinterherhinken“.

Es bedeutet:

> **Wir haben inzwischen genug Architektur und Code definiert, dass der nächste große Schritt nicht mehr Design ist, sondern das Zusammenschalten und reale Laufenlassen.**

Und genau deshalb ist die aktuelle Frage **ISR ↔ Switches** gerade ziemlich wertvoll. Das ist keine Nebensache mehr, sondern eine der letzten Architekturentscheidungen, bevor aus einzelnen Codebausteinen langsam ein echter FY-Controller wird.

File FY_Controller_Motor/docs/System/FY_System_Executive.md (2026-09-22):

# FY System Executive – Mini-Scheduler

> **Arbeitsdokument / Architektur**
>
> Das FY System Executive ist bewusst kein RTOS und kein allgemeines Betriebssystem.
> Es ist eine kleine, auf den Fiddle Yard UVB zugeschnittene Ablaufsteuerung.

Parent Issue: #42 System  
Child Issue: #96 SYS – FY System Executive / Mini-Scheduler

## 1. Grundidee

Der Arduino-Loop soll nicht selbst verstreute Ablaufsteuerung enthalten.

Zentraler Einstieg:

```cpp
void loop()
{
    FY_System.update();
}
```

Das Executive verteilt die vorhandene Zeit auf wenige klar definierte Aufgaben.

## 2. Ausführungsklassen

| Klasse | Beispiele | Mechanismus |
|---|---|---|
| ⚡ Echtzeit | STEP, Position, unmittelbare Sensorreaktion | Timer1 ISR |
| 🔄 Event | UART-Kommandos, MotorJob, STOP | System-/Loop-Kontext |
| ⏱️ Periodisch | Taster, Display, ALIVE | `millis()` |
| 💤 Hintergrund | Diagnose, optionale Pflegearbeiten | Idle |

## 3. Gesamtarchitektur

```mermaid
flowchart TD

    LOOP["loop()"]
    SYS["FY System Executive"]

    UART["UART<br/>RX / Commands"]
    KB["Keyboard<br/>Buttons / Events"]
    DISP["Display<br/>Dirty → Update"]
    MOTOR["Motor"]
    ISR["Timer1 ISR<br/>STEP / Position / Sensor"]
    ALIVE["ALIVE<br/>500 ms"]
    IDLE["Idle / Diagnose"]

    LOOP --> SYS

    SYS --> UART
    SYS --> KB
    SYS --> DISP
    SYS --> MOTOR
    SYS --> ALIVE
    SYS --> IDLE

    MOTOR --> ISR
    ISR --> MOTOR

    UART -. "später optional<br/>RX Interrupt" .-> UART
```

**Lesart:**

- Durchgezogene Verbindungen = normaler Ablauf im System.
- Gestrichelte Verbindung = bewusst nur als spätere Erweiterung vorgesehen.
- Timer1/ISR ist vom normalen Systemzyklus getrennt.

## 4. Motorablauf

```mermaid
flowchart TD
    IN["UART / Keyboard"]
    JOB["MotorJob"]
    PREP["Motor.prepare()"]
    PROF["calcProfile()"]
    START["Motor startet"]
    ISR["Timer1 ISR"]
    STEP["STEP / Position / Sensor"]
    DONE["DONE"]

    IN --> JOB
    JOB --> PREP
    PREP --> PROF
    PROF --> START
    START --> ISR
    ISR --> STEP
    STEP --> DONE
```

Der normale Systemzyklus startet und überwacht die Motorlogik nur dort, wo dies außerhalb der Echtzeit-Ausführung erforderlich ist.

Der eigentliche Bewegungsablauf läuft nach dem Start über Timer1.

`Motor.update()` darf im Idle-Fall sehr billig sein und sofort zurückkehren.

## 5. Zeitbasis

Die periodischen Aufgaben verwenden eine gemeinsame `millis()`-Zeitbasis.

Richtwerte:

| Aufgabe | Zielintervall |
|---|---:|
| Keyboard | ca. 10–20 ms |
| Display-Prüfung | ca. 100 ms |
| ALIVE | ca. 500 ms |
| Diagnose / Hintergrund | ca. 1000 ms |

Die Werte sind keine harte Echtzeit-Spezifikation und können später angepasst werden.

Es gibt **keine blockierenden `delay()`-Aufrufe** im normalen Ablauf.

## 6. UART

Der aktuelle UART bleibt zunächst gepollt.

Die Architektur wird trotzdem so gehalten, dass später optional ein RX-Interrupt ergänzt werden kann:

```mermaid
flowchart LR
    RX["UART RX"]
    ISR["RX ISR"]
    BUF["RX-Puffer"]
    SYS["FY_System.update()"]
    DEC["UART decode / process"]
    MOTOR["MotorJob"]

    RX --> ISR
    ISR --> BUF
    BUF --> SYS
    SYS --> DEC
    DEC --> MOTOR
```

Der RX-Interrupt darf ausschließlich empfangene Bytes sicher in einen Puffer übernehmen.

**Nicht im RX-ISR:**

- Command-Ausführung
- Motorsteuerung
- Display-Aktualisierung
- komplexe Zustandslogik

ALIVE ist eine unabhängige periodische Systemaufgabe und hängt nicht am RX-Interrupt.

## 7. Keyboard und Display

### Keyboard

- nicht blockierend
- zyklische Abfrage
- vorhandene 50-ms-Entprellung bleibt erhalten
- STOP wird zuerst behandelt

### Display

Das Display arbeitet mit einem Dirty-Prinzip.

Nicht:

```
loop → immer Display neu zeichnen
```

sondern:

```
Statusänderung
    ↓
Display dirty
    ↓
periodische Prüfung
    ↓
Display aktualisieren
    ↓
dirty = false
```

Damit wird das OLED nicht unnötig ständig neu aufgebaut.

## 8. Switches und Sensoren

Die bereits getroffene Architekturentscheidung:

- Im normalen Main-/Loop-Kontext sind `digitalRead()` und `analogRead()` zulässig.
- Im Timer1-ISR-Kontext werden zeitkritische Signale direkt über AVR-Register gelesen.
- Der ISR-Code bleibt minimal und deterministisch.
- Sensorinterpretation erfolgt außerhalb der ISR, sofern keine unmittelbare Echtzeitreaktion erforderlich ist.
- Für die vorhandenen LM393-Gabelsensoren wird zunächst keine zusätzliche Filter-/Debounce-Logik im ISR vorgesehen.

Details siehe Issue #93.

## 9. Idle

Wenn keine dringende Arbeit anliegt, darf ein einfacher Idle-/Diagnose-Slot ausgeführt werden.

Der Idle-Slot ist ausdrücklich **kein zweiter Scheduler**.

Es gibt:

- keine Task-Objekte
- keine Threads
- keine Prioritätsverwaltung
- keine Semaphore/Mutex
- keine komplexen Message Queues
- keine dynamische Speicherverwaltung

## 10. Was dieses „FY-OS“ ausdrücklich nicht ist

Das System Executive ist kein OSEK/RTOS.

Der Begriff „OS“ beschreibt hier nur die Rolle als zentraler Ablaufverwalter.

Ziel ist:

> **So viel Systemsteuerung wie nötig – so wenig Framework wie möglich.**

## 11. Geplanter Aufbau

Kleinste sinnvolle Umsetzung:

1. `FY_System.update()` als zentralen Zyklus einführen.
2. Gemeinsame `millis()`-Zeitbasis ergänzen.
3. UART und Keyboard als Event-Quellen einbinden.
4. Display-Dirty-Prinzip anbinden.
5. ALIVE als periodische Aufgabe ergänzen.
6. MotorJob/Motorzustand anbinden.
7. Idle/Diagnose als letzten optionalen Slot ergänzen.
8. Erst danach prüfen, ob ein UART-RX-Interrupt überhaupt erforderlich ist.

## 12. Zielbild

```mermaid
flowchart TB

    LOOP["loop()"]
    SYS["FY System Executive"]

    EVENT["Event-Verarbeitung"]
    PERIODIC["Periodische Aufgaben"]
    IDLE["Idle"]

    UART["UART"]
    KEY["Keyboard"]
    MOTOR["Motor"]
    DISPLAY["Display"]
    ALIVE["ALIVE"]
    DIAG["Diagnose"]

    TIMER["Timer1 ISR"]
    STEP["STEP / Position / Sensor"]

    LOOP --> SYS

    SYS --> EVENT
    SYS --> PERIODIC
    SYS --> IDLE

    EVENT --> UART
    EVENT --> KEY
    EVENT --> MOTOR

    PERIODIC --> DISPLAY
    PERIODIC --> ALIVE

    IDLE --> DIAG

    MOTOR --> TIMER
    TIMER --> STEP
    STEP --> MOTOR
```

Damit entsteht eine klare Trennung:

**System Executive organisiert – Timer1 führt Echtzeit aus – Module machen ihre eigentliche Arbeit.**

## 13. Status

🟢 **Architektur entschieden**

🟡 **Implementierung offen**

⚪ **UART-RX-Interrupt bewusst später**

⚪ **Idle zunächst optional**

Die Datei beschreibt den aktuellen Architekturstand und darf sich mit der Implementierung weiterentwickeln.

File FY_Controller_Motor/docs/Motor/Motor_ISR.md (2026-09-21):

# Motor ISR – Profil-Executor

> Dokumentation der aktuellen Timer1-ISR-Ausführung.  
> Zugehöriges GitHub Issue: #51 – M7 Timer1 / STEP-Erzeugung, ISR und Motor-Execution.

## Grundprinzip

Die Timer1-ISR arbeitet ein **bereits vorbereitetes MotorProfile** ab.

Die Prepare-Funktionen erzeugen:
- die logische Fahrtrichtung
- die Profiltabelle mit den sechs Segmenten

Die ISR berechnet **kein neues Bewegungsprofil**. Sie führt die Profiltabelle Schritt für Schritt aus.

Die Abarbeitung endet, sobald:
1. das Profil vollständig abgearbeitet ist oder
2. ein Endschalter auslöst.

## Ablauf

```mermaid
flowchart TD
    A["Timer1 ISR"] --> B{"Motorprofil aktiv?"}

    B -- Nein --> Z["ISR Ende"]

    B -- Ja --> C{"Neuer Job übernommen?"}

    C -- Ja --> D["DIR aus MotorProfile.direction setzen<br/>Registerzugriff"]
    C -- Nein --> E["Aktuelles Profilsegment verwenden"]

    D --> E

    E --> F["STEP ausführen<br/>Registerzugriff"]
    F --> G["Position ±1<br/>gemäß logischer Direction"]

    G --> H{"Endschalter LOW?"}

    H -- Ja --> I["STOP_BY_SWITCH<br/>Profil abbrechen"]
    I --> J["Timer/STEP stoppen"]
    J --> Z

    H -- Nein --> K["Aktuelles Segment<br/>Rest-STEPs −1"]

    K --> L{"Segment fertig?"}

    L -- Nein --> Z

    L -- Ja --> M{"Weiteres Profilsegment?"}

    M -- Ja --> N["Zum nächsten Segment wechseln"]
    N --> Z

    M -- Nein --> O["STOP_BY_PROFILE<br/>Profil vollständig abgearbeitet"]
    O --> J

    Z --> A
```

## Profiltabelle und Segmentwechsel

Die Profiltabelle wird außerhalb der ISR vorbereitet:

```text
MotorProfile
├── direction
└── profile[]
    ├── ACC1
    ├── ACC2
    ├── KONST
    ├── BRE1
    ├── BRE2
    └── POSI
```

Die ISR hält den aktuellen Segmentzustand und arbeitet die dort vorgegebene Anzahl von STEP-Intervallen ab.

Nach dem letzten STEP eines Segments:
- Rest-STEPs werden aktualisiert,
- falls weitere Segmente vorhanden sind, wird auf das nächste Segment gewechselt,
- andernfalls wird `STOP_BY_PROFILE` gesetzt und die Bewegung beendet.

## Endschalter

- Endschalter werden nach jedem ausgeführten STEP geprüft.
- Aktiv ist der Zustand `LOW`.
- Ein Endschalter ist zunächst ein **physischer Bewegungsstopp**, nicht automatisch ein Fehler.
- Wird der Endschalter vor dem Profilende erreicht: `STOP_BY_SWITCH`.
- Wird der Endschalter auf dem letzten STEP gleichzeitig mit dem Profilende erreicht, hat `STOP_BY_PROFILE` Priorität.

## Zuständigkeiten

### Prepare-Funktionen
- Ziel und Bewegungsrichtung bestimmen
- `MotorProfile.direction` setzen
- Profiltabelle erzeugen
- Bewegung vorbereiten

### Timer1-ISR
- neuen vorbereiteten Job übernehmen
- physische DIR setzen
- STEP erzeugen
- Position fortschreiben
- Endschalter prüfen
- aktuelles Profilsegment abarbeiten
- Segmentwechsel durchführen
- bei Profilende oder Endschalter sicher stoppen

### Außerhalb der ISR
- UART / Kommunikation
- Anwendungsspezifische Fehlerinterpretation
- Entscheidung, ob `STOP_BY_SWITCH` im jeweiligen Kontext ein Fehler ist

## Hardwarezugriff

STEP und DIR werden im zeitkritischen Pfad direkt über Registerzugriffe bedient.

Die physische DIR-Polarität wird über `MOTOR_DIR_INVERTED` berücksichtigt.

Die Position wird anhand der **logischen Richtung** fortgeschrieben, nicht anhand des elektrischen DIR-Pinpegels.

## Referenzen

- GitHub Issue #51: M7 – Timer1 / STEP-Erzeugung, ISR und Motor-Execution
- Prepare-Funktionen: #24, #75, #76
- Profilberechnung: #23
- Motor Status/Position: #52

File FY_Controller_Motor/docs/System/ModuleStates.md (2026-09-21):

# Module States – FY Controller

> **Arbeitsdokument / erster Stand**
>
> Diese Datei ist eine systemweite Übersicht der aktuell im Code definierten Zustandsmaschinen.
> Die eigentliche Zustandsdefinition bleibt jeweils im zuständigen Modul.
>
> Die Übersicht darf sich ändern, wenn Zustände umbenannt, ergänzt, verschoben oder in
> Zustandsmaschine und Statusinformation sauberer getrennt werden.

## 1. System – \`FY_SystemState_t\`

Quelle: \`FY_Controller_Motor/include/FY_System.h\`

```mermaid
stateDiagram-v2
    [*] --> INIT
    INIT --> REF
    REF --> Idle
    Idle --> Busy
    Busy --> Idle
    Busy --> Error
    Idle --> Error
    Error --> INIT
```

Aktuell definierte Zustände:

- \`INIT\` – Systeminitialisierung nicht abgeschlossen
- \`REF\` – System befindet sich im Referenzzustand
- \`Idle\` – System wartet auf Befehle
- \`Busy\` – System bearbeitet eine Aufgabe
- \`Error\` – System befindet sich im Fehlerzustand

---

## 2. Motor – \`MotorState_t\`

Quelle: \`FY_Controller_Motor/lib/Motor/Motor.h\`

```mermaid
stateDiagram-v2
    [*] --> IDLE
    IDLE --> CONF
    CONF --> REFRUN
    CONF --> MOVING
    MOVING --> STOPPED
    MOVING --> ERROR
    REFRUN --> STOPPED
    REFRUN --> ERROR
    STOPPED --> IDLE
    STOPPED --> MOVING
    ERROR --> IDLE
```

Aktuell definierte Zustände:

- \`IDLE\`
- \`CONF\`
- \`REFRUN\`
- \`MOVING\`
- \`STOPPED\`
- \`ERROR\`

Die konkrete Übergangslogik ist noch nicht als verbindliche Gesamt-Zustandsmaschine festgelegt.
Das Diagramm zeigt daher den aktuellen Arbeitsstand und ist **nicht** als endgültige Spezifikation zu verstehen.

---

## 3. Referenzierung – \`REF_STATE\`

Quelle: \`FY_Controller_Motor/include/FY_System.h\`

```mermaid
stateDiagram-v2
    [*] --> REF_REQ
    REF_REQ --> REFR_EXEC
    REFR_EXEC --> REF_VALID
    REFR_EXEC --> REF_ERROR
    REF_ERROR --> REF_REQ
    REF_VALID --> REF_REQ
```

Aktuell definierte Zustände:

- \`REF_REQ\` – Referenzierung erforderlich / angefordert
- \`REFR_EXEC\` – Referenzlauf läuft
- \`REF_VALID\` – Referenzierung erfolgreich
- \`REF_ERROR\` – Referenzierung fehlgeschlagen

**Wichtig:** Diese Zustände sind keine Fehlercodes. Insbesondere \`REFR_EXEC\` und \`REF_VALID\`
werden über den normalen Statusweg (z. B. \`GETSTATUS\`) abgefragt bzw. gemeldet.

---

## 4. UART – Empfang – \`ReceiveState\`

Quelle: \`FY_Controller_Motor/lib/UART/UART.h\`

```mermaid
stateDiagram-v2
    [*] --> FindCommand
    FindCommand --> ReadData
    ReadData --> CheckCRC
    CheckCRC --> FindCommand
    CheckCRC --> ReadData
```

Aktuell definierte Zustände:

- \`FindCommand\`
- \`ReadData\`
- \`CheckCRC\`

---

## 5. UART – Command-Ergebnis – \`UART_CommandStatus_t\`

Quelle: \`FY_Controller_Motor/lib/UART/UART.h\`

```mermaid
stateDiagram-v2
    [*] --> VALID
    VALID --> CMD_INVALID
    VALID --> DATA_INVALID
    VALID --> CRC_INVALID
```

Aktuell definierte Ergebnisse:

- \`VALID\`
- \`CMD_INVALID\`
- \`DATA_INVALID\`
- \`CRC_INVALID\`

Diese Werte sind aktuell als Command-Ergebnis definiert und werden bei der weiteren
Fehlercode-Architektur noch gegen die systemweiten Error-Codes abgegrenzt.

---

## 6. Endschalter / Positionssensorik

Aktuell ist hierfür noch keine eigenständige Zustandsmaschine im Code definiert.

Sobald die Sensorlogik als eigenes Modul mit eigenen Zuständen vorliegt, wird sie hier als
eigenes Kapitel ergänzt.

---

## 7. Systemweite Übersicht

```mermaid
flowchart TB
    SYS["System<br/>FY_SystemState_t"]
    MOTOR["Motor<br/>MotorState_t"]
    REF["Referenzierung<br/>REF_STATE"]
    UART_RX["UART Empfang<br/>ReceiveState"]
    UART_CMD["UART Command<br/>UART_CommandStatus_t"]
    SENSOR["Endschalter / Sensorik<br/>noch offen"]

    SYS --> MOTOR
    SYS --> REF
    SYS --> UART_RX
    UART_RX --> UART_CMD
    MOTOR --> REF
    MOTOR --> SENSOR
```

### Grundsatz

Die Diagramme in dieser Datei sind eine **Übersicht**, keine zweite Quelle der
Zustandsdefinition.

Die fachliche Definition eines Zustands bleibt beim jeweiligen Modul:

- System → \`FY_System.h\`
- Motor → \`Motor.h / motor.cpp\`
- UART → \`UART.h / UART.cpp\`
- Referenzierung → zuständige Referenzierungslogik
- Sensorik → zuständiges Sensor-/Endschaltermodul

Diese Datei dient dazu, beim Systemdesign schnell erkennen zu können, **welche
Zustandsmaschinen existieren und wie sie zueinander stehen**.

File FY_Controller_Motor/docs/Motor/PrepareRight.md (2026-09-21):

# MOTOR – Prepare RIGHT Flow

Flow of the motor preparation logic for a RIGHT movement.

The flow mirrors the LEFT preparation logic in the opposite direction.

The **first check is always the logical motor power state**. If the motor is OFF, no movement profile is prepared. The motor power state is tracked separately from the reference state; see **#86 – Motor Enable / Disable und Referenzverlust**.

```mermaid
flowchart TD

    M{Motor ON?}
    M -->|NO| G[return false]
    M -->|YES| B{MOTOR Busy}

    B -->|YES| G
    B -->|NO| A{Referenziert?}

    A -->|No| C{Requested Steps <= 200?}
    C -->|No| G
    C -->|Yes| K{ENDSCHALTER RIGHT aktiv?}

    A -->|Yes| E{Requested Steps <= available RANGE?}
    E -->|No| G
    E -->|Yes| K

    K -->|Yes| G
    K -->|No| L[CALC_PROFILE]
    L --> D[Start Timer]
    D --> R[return true]
```

Die LEFT- und RIGHT-Flows sind bewusst gespiegelt, damit die Richtungslogik beim Coding eindeutig bleibt.

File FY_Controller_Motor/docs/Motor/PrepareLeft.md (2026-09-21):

# MOTOR – Prepare LEFT Flow

Flow of the motor preparation logic for a LEFT movement.

The flow is intentionally used as a **coding guide**: it defines the decision order and makes safety/definition gaps visible before implementation.

The **first check is always the logical motor power state**. If the motor is OFF, no movement profile is prepared. The motor power state is tracked separately from the reference state; see **#86 – Motor Enable / Disable und Referenzverlust**.

```mermaid
flowchart TD

    M{Motor ON?}
    M -->|NO| G[return false]
    M -->|YES| B{MOTOR Busy}

    B -->|YES| G
    B -->|NO| A{Referenziert?}

    A -->|No| C{Requested Steps <= 200?}
    C -->|No| G
    C -->|Yes| K{ENDSCHALTER LEFT aktiv?}

    A -->|Yes| E{Requested Steps <= available RANGE?}
    E -->|No| G
    E -->|Yes| K

    K -->|Yes| G
    K -->|No| L[CALC_PROFILE]
    L --> D[Start Timer]
    D --> R[return true]
```

`PrepareRight.md` soll sinngemäß gespiegelt folgen.

Die Diagramme dienen außerdem als Grundlage für die Visualisierung des Reference-Runs und machen fehlende oder noch nicht eindeutig definierte Entscheidungen vor dem Coding sichtbar.

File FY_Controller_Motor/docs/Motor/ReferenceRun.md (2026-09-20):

# MOTOR – PREFRUN first version

Erstes Diagramm für den Reference-Run. 

Der Flow ist bewusst eine erste Version. Offene Detailentscheidungen bleiben sichtbar und werden vor der Implementierung geklärt.

```mermaid
flowchart TD

    A[Reference aufgerufen?]

    A --> B{Motor IDLE?}

    B -->|Nein| X[Reference ablehnen]

    B -->|Ja| C{Referenz bereits gültig?}

    C -->|Ja| Y[Referenzdaten löschen]

    C -->|Nein| D{END_LEFT aktiv?}

    Y --> D

    D -->|Ja| E[Escape: ca. 30 Steps nach RIGHT]

    E --> I{ENDschalter L frei?}

    I -->|Ja| F[Langsam nach LEFT fahren]

    I -->|Nein| O[REF_ERROR]

    D -->|Nein| F

    F --> G{END_LEFT erreicht?}

    G -->|Ja| H[Position = linker mechanischer Endpunkt]

    G -->|Nein| F

    H --> K[Langsam nach RIGHT fahren]

    K --> L{REFERENCE erkannt?}

    L -->|Ja| M[REFERENCE Position merken]

    L -->|Nein| N{END_RIGHT erreicht?}

    N -->|Nein| K

    N -->|Ja| O

    M --> P[Weiter nach RIGHT bis END_RIGHT]

    P --> Q[Gesamtstrecke ermitteln]

    Q --> R[Bewegungsbereich berechnen]

    R --> S[POS_MIN / POS_MAX festlegen]

    S --> T[Reference gültig]

    T --> U[REF_VALID]
```

## Offen

- Abbruch rechts, wenn der Endschalter nicht innerhalb der mathematisch erwarteten Maximalstrecke gefunden wird.
- Schleife für das Erkennen der Referenzfahne: `LOW / HIGH / LOW`.
- Speichern der Breite der Referenzfahne in Steps.

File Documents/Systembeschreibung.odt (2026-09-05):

Systembeschreibung

Start 05.09.26

letzte Speicherung:05.09.26

1. Mechanik
  - Brücke
  - Linearführungen
  - Spindel/Riemen
  - Motor
  - End-/Referenzsensoren
  - Gleispositionen
2. Elektronik
  - STM32/Arduino/ESP32
  - Stepper-Treiber
  - Hall-Sensoren
  - Taster
  - Display
  - Pegelwandler/ULN usw.
3. Firmware
  - Motorsteuerung
  - Beschleunigungs-/Bremsrampe
  - Positionierung
  - ISR
  - Zustandsmaschine
  - Fehler-/STOP-Behandlung
4. Bedienung & Kommunikation
  - lokales Bedienfeld
  - Display
  - UART
  - später ESP32/Weboberfläche
  - MQTT bzw. Verbindung zum restlichen System
5. Schnittstelle zum Gesamtsystem
  - Welche Befehle bekommt das FY?
  - Welche Statusinformationen liefert es zurück?
  - Wer ist „Herr der Position“?
  - Was passiert bei Neustart oder Referenzverlust?

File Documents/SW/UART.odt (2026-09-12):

Beschreibung Uart

12.09.26

# Aufgabe

Das Uart Modul soll die Verwaltung der Kommunikation übernehmen.

# Formate

Eine Befehl besteht aus zwei Teilen.

1. CMD ID
2. Daten

Eine Antwort besteht auch aus zwei Teilen

1. RESP ID
2. Daten

desweiten gibt es drei Typen von Befehlen

1. Intermediate
2. Exclusive
3. Priority

# Verhalten

Von der seriellen Schnittstelle werden die Befehle empfangen.

Diese werden direkt beantwortet.

Es wird der nächste Befehl erst akzeptiert , nach dem die Antwort gesendet wurde.
Der Sender hat sicherzustellen das diese Anforderung eingehalten wird.

Priorty Befehle können jederzeit abgesetzte werden und werden direkt umgesetzt. Sie sind Einbyte Befehle ohne Daten.

Die nachfolgende Tabellen zeigt die CMD ID und zugehörigen die Resp ID geordnet nach dem Typen

## Intermediate Befehle und Antworten

CMD ID | Resp ID | Daten | Bemerkung/Bedingung
CMD_GET_STATUS | STATUS_System | System Statusbyte Status_Motor Status_LOKAL/REMOTE
CMD_GET_ERROR | STATUS_ERROR | System_errorbyte <TBD>
CMD_GET_POSITION | STATUS_Position | PositionReached /NotReached akt. Position
CMD_GET_TRACK | STATUS_Track | Track number STATUS_TrackNotSet/ TrackSet TrackNotReached TrackReached
CMD_HELP | STATUS_Help | Help String | Sendet diese Tabellen je nach implementierung

## Execute Befehle und Antworten

CMD ID | Daten | | Resp ID | Daten | Bemerkung
CMD_REFERENCE | | | STATUS_Reference | STATUS_ReferenceDONE STATUS_ReferenceNotDONE
CMD_SET_SPEED | Steps | Step/s | STATUS_Motor | Speed Position STATUS_Reference
CMD_GO | | | STATUS_ACK | STATUS_OK/ STATUS_busy/ OUTof_Rrange
CMD_LEFT | | Steps | STATUS_ACK | STATUS_OK/ STATUS_busy/ OUTof_Rrange
CMD_RIGHT | | Steps | STATUS_ACK | STATUS_OK/ STATUS_busy/ OUTof_Rrange
CMD_SET_POSITION | Steps | Steps Absolut | STATUS_ACK | STATUS_OK/ STATUS_busy/ OUTof_Rrange | Die Rampe von A nach B wird intern berechnet
CMD_SET_TRACK | | | STATUS_ACK | STATUS_OK/ STATUS_busy/ OUTof_Rrange
CMD_SET_REMOTE | | | STATUS_CMD | STATUS_LOKAL/ STATUS_REMOTE
CMD_SET_LOCAL | | | STATUS_CMD | STATUS_LOKAL/ STATUS_REMOTE

## Priority Befehle und Antworten

CMD ID | Resp ID | Daten | Bemerkung
CMD_STOPP | STATUS_System | SystemStatusbyte

Die ID’s werden in der Protokoll.h defniert.

Die Elemente und Eigenschaften sind in UART.H und UART. CPP codiert

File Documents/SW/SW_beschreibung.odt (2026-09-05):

Softwarebeschreibung

Startdatum : 05.09.26

Speicherdatum : 05.09.26 17:49

# 1. Kommunikation

Übertragung der Daten ggf im Jason Format

UART – Command Interface (https://github.com/ErikaB-sys/Fiddle_yard_UVB/issues/6)

- UART-Protokoll für ESP32 definieren
- Befehlsformat festlegen
- Befehle für:
- MOVE
- STOP
- HOME
- STATUS
- GET_POSITION
- ggf. RESET
- Parameter und Rückgabewerte definieren
- Fehlercodes definieren
- ACK/NACK-Verhalten festlegen

### UART – State Interface (https://github.com/ErikaB-sys/Fiddle_yard_UVB/issues/7)

Aktuellen Zustand des FY übertragen

- Motorstatus
- aktuelle Position
- Zielposition
- Referenzstatus
- Fehlerstatus
- Bewegung abgeschlossen (DONE)
- Fehler (ERROR)
- STOP ausgelöst

# 2. Motor Control Module

### Motor Control – Step/Direction/Enable

- Ansteuerung des Stepper-Treibers
- STEP
- DIR
- ENABLE
- definierte Zustände beim Einschalten
- Motor deaktivieren bei Fehler/Stillstand

### Movement Control – Positioning

Das ist der eigentliche Bewegungsalgorithmus.

- Startposition
- Zielposition
- Bewegungsrichtung
- Anzahl Schritte berechnen
- Bewegung starten
- Bewegung beenden
- Position aktualisieren
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

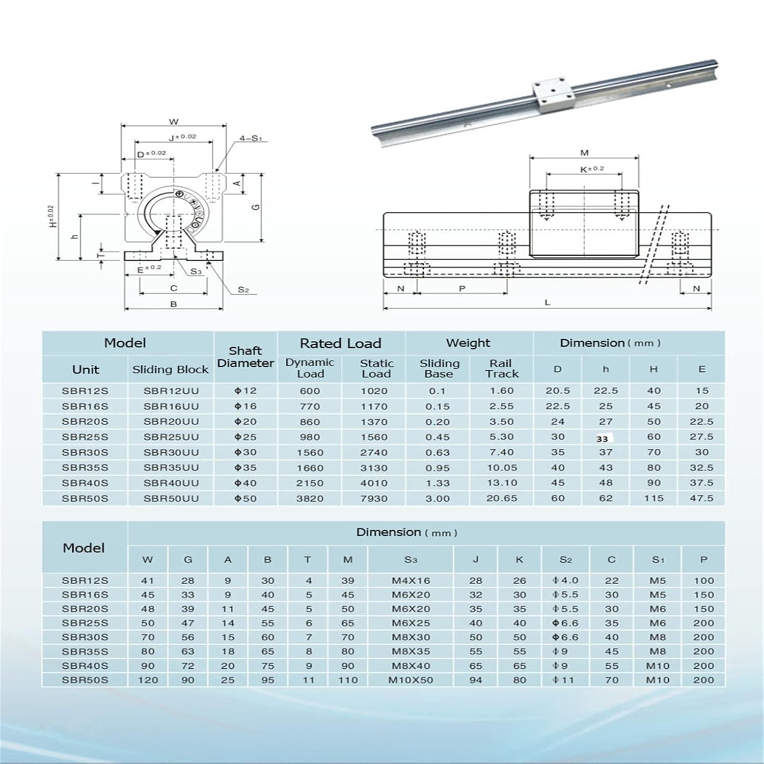
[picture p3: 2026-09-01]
Documents/Datasheets/Schiene_part1.jpg

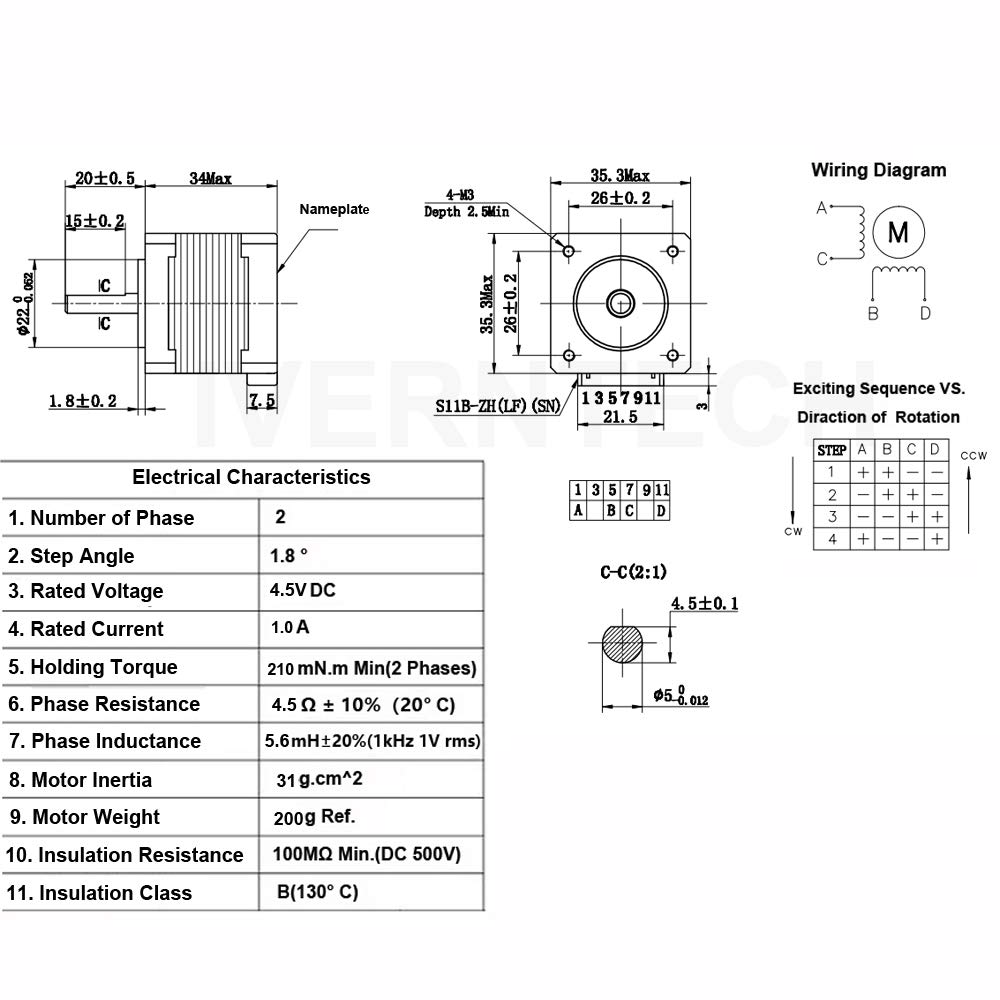
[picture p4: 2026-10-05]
Documents/Motor/61058V9tn0L._SL1000_.jpg

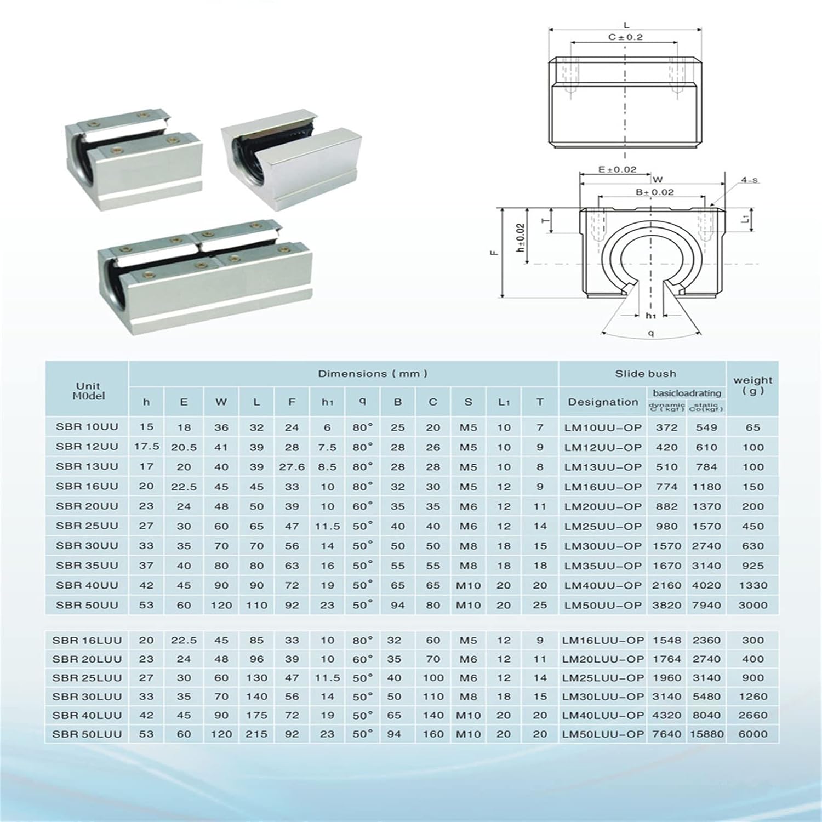
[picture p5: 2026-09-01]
Documents/Datasheets/Schiene_part2.jpg

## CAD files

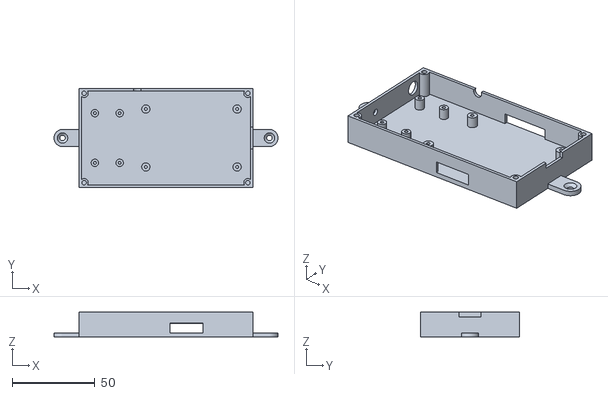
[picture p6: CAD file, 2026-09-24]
Parts/Schiebebbühne/Arduino_Gehäuse/Arduino_gehäuse-Unterteil mit Phasen .stl
135.4 x 60.0 x 15.0

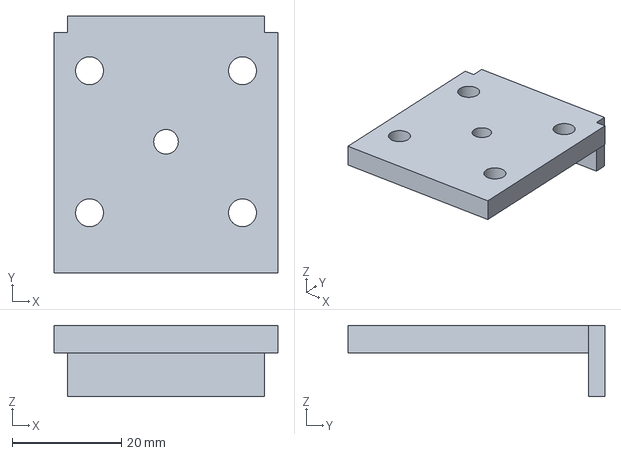
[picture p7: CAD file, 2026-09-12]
Parts/Schiebebbühne/Bohrlehre/Bohrlehre.FCStd
41.0 x 47.0 x 13.0 mm

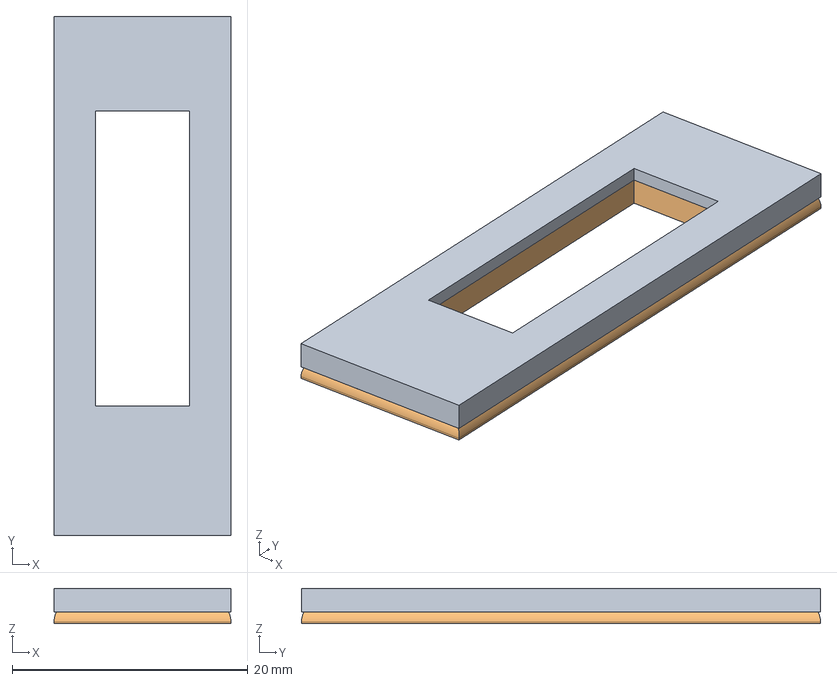
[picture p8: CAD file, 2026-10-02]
Parts/Schiebebbühne/KEYboard/Keyboard.FCStd
15.0 x 44.0 x 3.00 mm
displayabdeckung

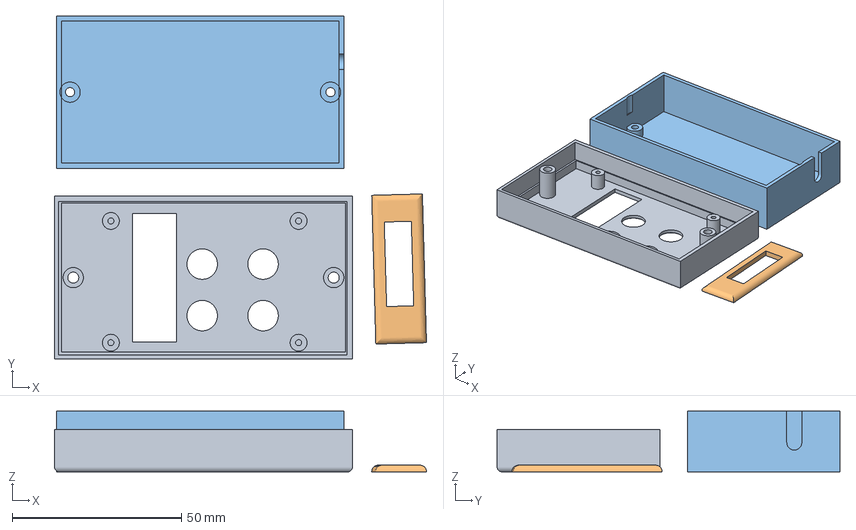
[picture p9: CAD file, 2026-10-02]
Parts/Schiebebbühne/KEYboard/stl/Keyboard-Frontplatte.3mf
110.0 x 101.4 x 18.0 mm
Keyboard-Frontplatte.stl
Keyboard-displayabdeckung.stl
Keyboard-Unterteil.stl

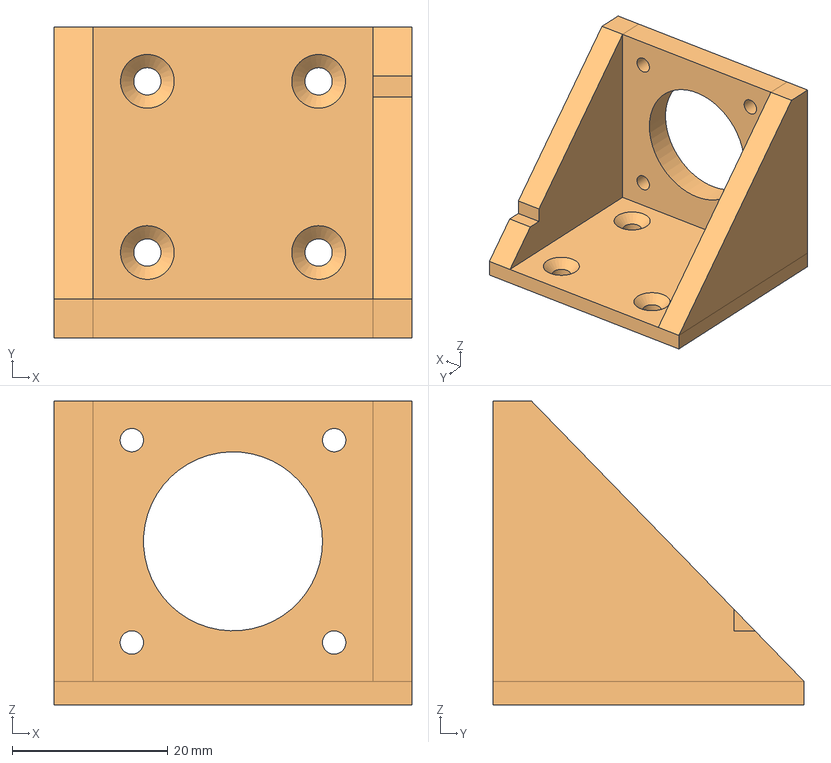
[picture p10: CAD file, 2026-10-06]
Parts/Schiebebbühne/Rolle/MotorhalterNEMA14.FCStd
46.0 x 40.0 x 39.0 mm
Bodenplatte

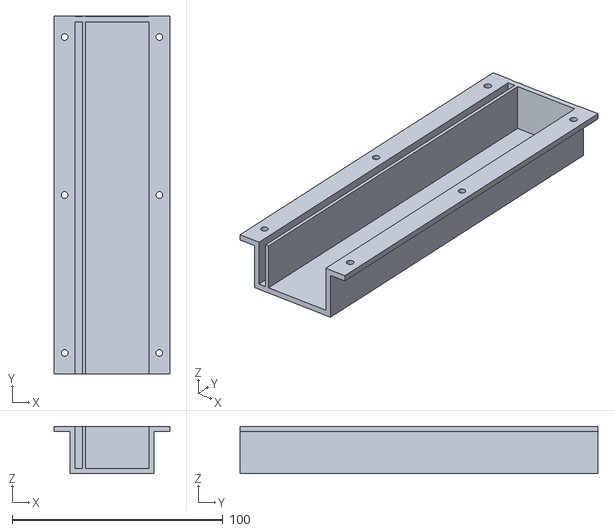
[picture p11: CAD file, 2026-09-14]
Parts/Schiebebbühne/Wanne_kabelkette/Wanne_kabelkette_Wanne.stl
55.0 x 170.0 x 22.5

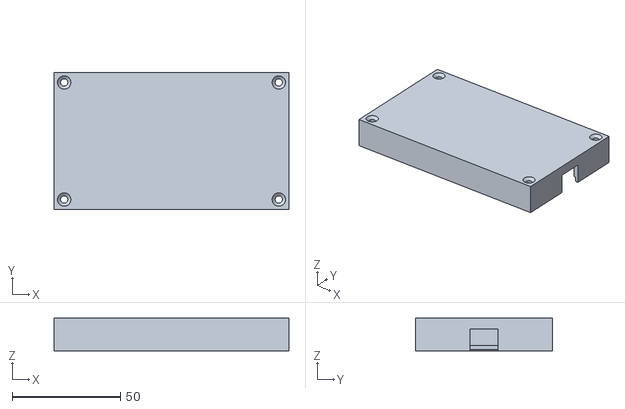
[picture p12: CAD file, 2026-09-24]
Parts/Schiebebbühne/Arduino_Gehäuse/Arduino_gehäuse-Deckel_m_Befestigungsbohrung.stl
108.4 x 63.4 x 15.0

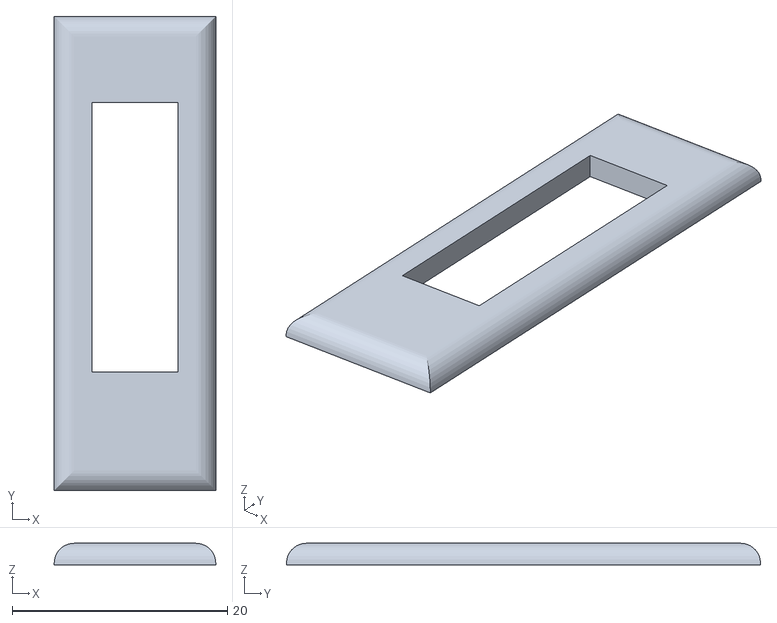
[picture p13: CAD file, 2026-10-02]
Parts/Schiebebbühne/KEYboard/stl/Keyboard-displayabdeckung.stl
15.0 x 44.0 x 2.00

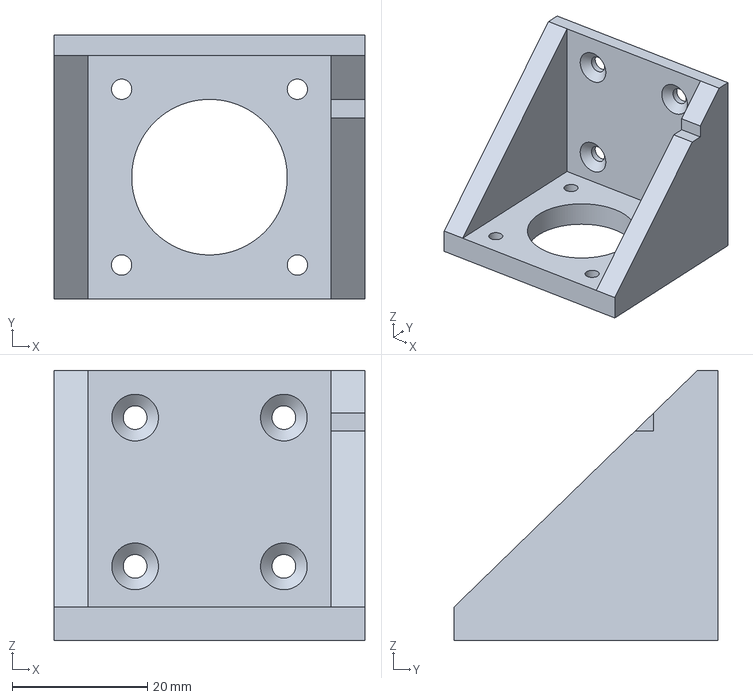
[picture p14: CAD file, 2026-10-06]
Parts/Schiebebbühne/Rolle/MotorhalterNEMA14-Cut.3mf
46.0 x 39.0 x 40.0 mm

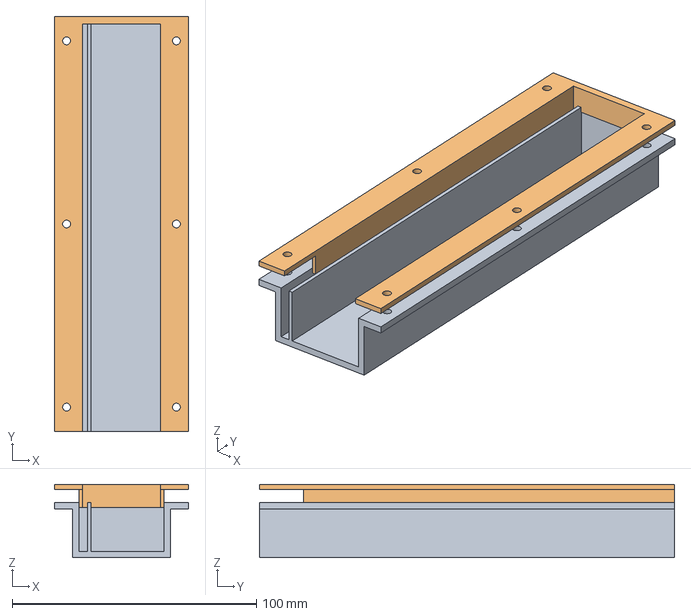
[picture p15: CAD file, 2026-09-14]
Parts/Schiebebbühne/Wanne_kabelkette/Wanne_kabelkette.FCStd
55.0 x 170.0 x 30.0 mm
Wanne
Abdeckung

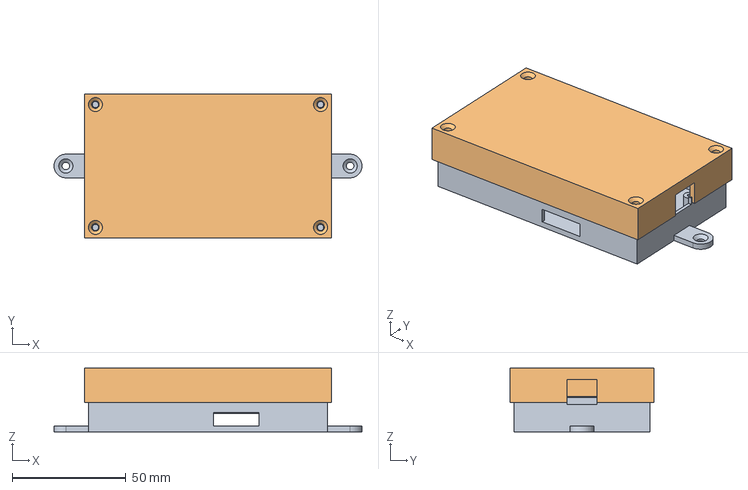
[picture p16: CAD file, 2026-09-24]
Parts/Schiebebbühne/Arduino_Gehäuse/Arduino_gehäuse.FCStd
135.4 x 63.4 x 28.0 mm
Unterteil mit Phasen
Deckel_m_Befestigungsbohrung

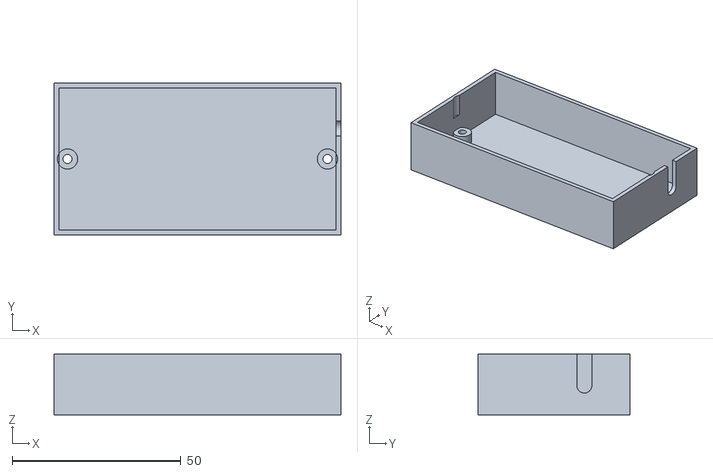
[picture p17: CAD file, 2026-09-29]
Parts/Schiebebbühne/KEYboard/stl/Keyboard-Unterteil.stl
85.0 x 45.0 x 18.0

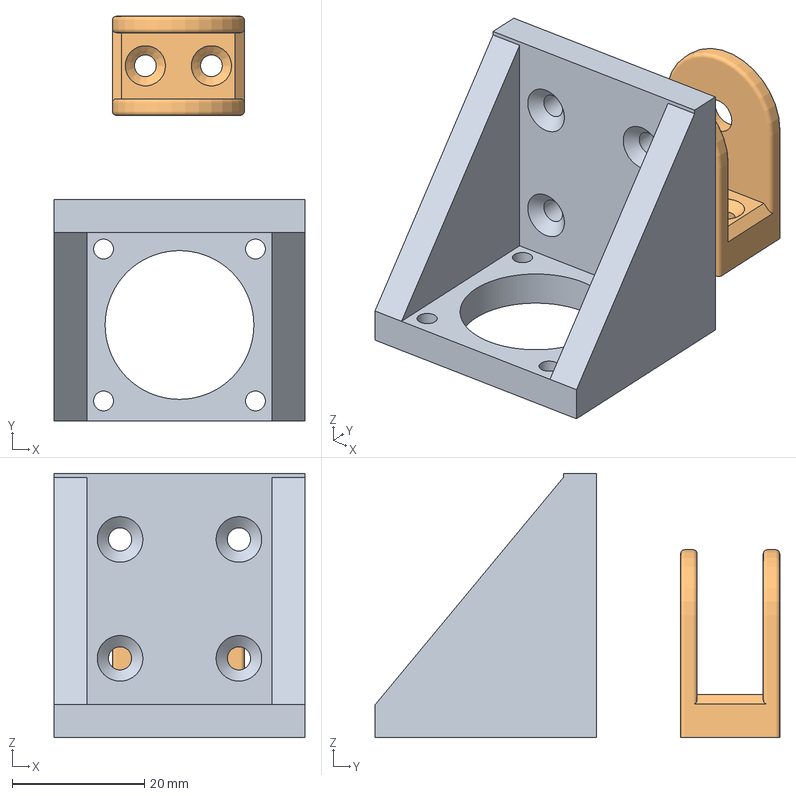
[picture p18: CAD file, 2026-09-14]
Parts/Schiebebbühne/Rolle/Rollenhalter-Chamfer.3mf
38.0 x 61.2 x 40.0 mm
Motorhalter-Compound.stl
Rollenhalter-Chamfer.stl

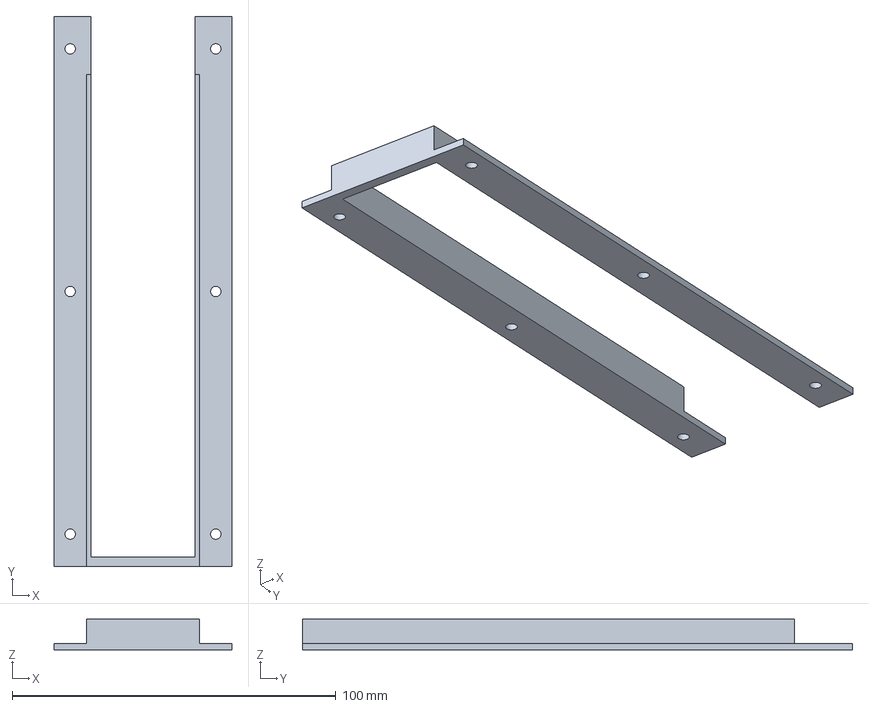
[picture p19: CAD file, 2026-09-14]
Parts/Schiebebbühne/Wanne_kabelkette/Wanne_kabelkette-Abdeckung.3mf
55.0 x 170.0 x 9.50 mm

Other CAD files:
Parts/Schiebebbühne/Bohrlehre/Bohrlehre-Fusion.3mf
Parts/Schiebebbühne/Arduino_Gehäuse/Arduino_gehäuse-Unterteil.3mf
Parts/Schiebebbühne/Rolle/Rollenhalter-Chamfer001.3mf
Parts/Schiebebbühne/Rolle/Rollenhalter-Spanner.3mf
Parts/Schiebebbühne/Arduino_Gehäuse/Arduino_gehäuse-Unterteil.stl
Parts/Schiebebbühne/Bohrlehre/Bohrlehre-Fusion.stl
Parts/Schiebebbühne/KEYboard/stl/Keyboard-Frontplatte.stl
Parts/Schiebebbühne/Rolle/Motorhalter-Compound.stl
Parts/Schiebebbühne/Rolle/Motorhalter.FCStd
Parts/Schiebebbühne/Rolle/MotorhalterNEMA14-Cut.stl
Parts/Schiebebbühne/Rolle/Rollenhalter-Chamfer.stl
Parts/Schiebebbühne/Rolle/Rollenhalter-Chamfer001.stl
Parts/Schiebebbühne/Rolle/Rollenhalter-Spanner.stl
Parts/Schiebebbühne/Rolle/Rollenhalter.FCStd
Parts/Schiebebbühne/Wanne_kabelkette/Wanne_kabelkette-Abdeckung.stl
Parts/Schiebebbühne/Wanne_kabelkette/Wanne_kabelkette.3mf

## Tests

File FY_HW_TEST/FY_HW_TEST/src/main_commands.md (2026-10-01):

# FY HW TEST – serielle Befehle

115200 Baud, Befehle mit CR/LF abschließen.

## Geschwindigkeit

| Befehl | Bedeutung |
|---|---|
| Vnnnn | VMAX in steps/s |
| vnnnn | VMIN in steps/s |

## Rampe

| Befehl | Bedeutung |
|---|---|
| A1n | Beschleunigungswert A1 |
| A2n | Beschleunigungswert A2 |
| B1n | Bremswert B1 |
| B2n | Bremswert B2 |
| A1Nn | Rampenintervall A1 |
| A2Nn | Rampenintervall A2 |
| B1Nn | Rampenintervall B1 |
| B2Nn | Rampenintervall B2 |

Bei den Rampenintervallen bedeutet N=1 Änderung nach jedem STEP, N=2 nach jedem zweiten STEP usw.

## Bewegung

| Befehl | Bedeutung |
|---|---|
| Snnnn | Bewegungsstrecke in Steps |

GO / LEFT / RIGHT / STOP erfolgen beim aktuellen HW-Test über die Taster.

## Track- und Positionsmodus

Die aktuell vermessenen Gleismitten sind als absolute Schrittpositionen im Programm hinterlegt:

| Track | Position |
|---|---:|
| BG1 | 1557 |
| BG2 | 3157 |
| BG3 | 4757 |
| BG4 | 6357 |
| BG5 | 7957 |

| Befehl | Bedeutung |
|---|---|
| T1 ... T5 | Track auswählen und die hinterlegte Position anfahren |
| T0 | Track-Modus verlassen |
| Pnnnn | absolute Position anfahren |

Bei T1 ... T5 wird die zugehörige Position aus dem Track-Array verwendet.

Pnnnn dient zum direkten Anfahren einer beliebigen absoluten Position. Damit können die gemessenen Trackpositionen experimentell überprüft und bei Bedarf Korrekturwerte ermittelt werden.

Die Positionierung erfolgt zunächst direkt vom aktuellen Standort zum Ziel. Eine definierte Anfahrrichtung bzw. automatische Richtungsumkehr ist derzeit nicht implementiert.

Für T und P muss der Motor mit dem GO-Taster aktiviert sein.

## Referenzlauf

| Befehl | Bedeutung |
|---|---|
| R oder r | Referenzlauf starten |
| K oder k | Referenzlauf starten |

Vor R / K muss der Motor mit dem GO-Taster aktiviert sein.

## Referenz-Messdaten

Der Referenzlauf ermittelt schrittweise:

- grobe Position der Referenzfahne beim Lauf L → R
- Position der rechten Fahnenkante beim langsamen Rücklauf R → L
- Position der linken Fahnenkante beim langsamen Rücklauf
- Fahnenlänge in Steps
- Mittelpunkt der Fahne
- Abweichung der groben Position vom gemessenen Mittelpunkt
- Position der rechten Endlage
- nutzbare Strecke zwischen linker und rechter Endlage

Die Ergebnisse werden nach Abschluss des Messlaufs einmal kompakt über UART ausgegeben.

## Speicherprinzip

Serielle Texte im AVR-Code werden mit F("...") im Flash gehalten. Die Messwerte selbst werden nur als numerische Werte gespeichert; keine dynamischen Strings.

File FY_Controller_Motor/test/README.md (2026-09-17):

# Tests
This directory is intended for PlatformIO Test Runner and project tests.

Unit Testing is a software testing method by which individual units of
source code, sets of one or more MCU program modules together with associated
control data, usage procedures, and operating procedures, are tested to
determine whether they are fit for use. Unit testing finds problems early
in the development cycle.

More information about PlatformIO Unit Testing:
- https://docs.platformio.org/en/latest/advanced/unit-testing/index.html
## Teststruktur

Die Tests werden nach Modulen organisiert.

```text
 test/
 ├── Motor/
 │   ├── test_calcProfile.cpp
 │   ├── test_prepareParameter.cpp
 │   └── test_State.cpp
 └── UART/
     ├── test_Command.cpp
     └── test_CRC.cpp
```

### Regeln

- Das Verzeichnis unter `test/` bezeichnet das Modul, zu dem der Test gehört.
- Der Dateiname beschreibt eindeutig den Testgegenstand, z. B. `test_calcProfile.cpp` für `calcProfile()`.
- Ein Testfile behandelt einen klar abgegrenzten Testgegenstand.
- Mehrere einzelne Testfälle dürfen innerhalb eines Testfiles vorhanden sein.
- Die Produktionsimplementierung wird nicht verändert, nur um einen Test zu ermöglichen. Tests passen sich an die bestehende bzw. bewusst definierte Produktionsschnittstelle an.
- Private interne Daten bleiben privat. Ein Test darf keine Produktionsschnittstelle allein deshalb aufbrechen, damit er interne Implementierungsdetails direkt auslesen kann.

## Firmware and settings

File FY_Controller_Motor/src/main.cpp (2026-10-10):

#include "FY_System.h"
#include "HW_Config.h"
#include "Main.h"
#include "Protokoll.h"
#include "Motor.h"
#include "UART.h"
#include "Error.h"
#include "Keyboard.h"
#include "Switches.h"
#include "Firmware.h"

FY_SystemInitStatus_t FY_System;

Switches       FY_Switches;
UART           FY_uart;
Motor          FY_motor;
Keyboard       FY_Keyboard;
Error          FY_Error;
UART_Context_t Main_Context;

FY_SystemStatus_t systemStatus;
FY_ModuleContext_t FY_Modules{};

void printFirmwareInfo()
{
  Serial.print(F("FW: "));
  Serial.println(FW_NAME);

  Serial.print(F("VER: "));
  Serial.println(FW_VERSION);

  Serial.print(F("BUILD: "));
  Serial.print(FW_BUILD);
  Serial.print(F(" "));
  Serial.println(FW_TIME);

  Serial.print(F("GIT: "));
  Serial.println(FW_GIT_COMMIT);
}

void setup()
{
  Main_Context.systemStatus = &systemStatus;
  Main_Context.error = &FY_Error;
  Main_Context.motorPosition = nullptr;
  Main_Context.Track_INFO = nullptr;
  Main_Context.motorSpeed = nullptr;

  FY_Modules = {
      &FY_motor,
      &FY_uart,
      &FY_Keyboard,
      &FY_Switches
  };

  FY_Error.begin();

  FY_uart.begin(Main_Context, FY_Modules);

  FY_motor.begin();

  FY_Keyboard.begin();
  FY_Keyboard.setMode(systemStatus.mode);

  FY_Switches.begin();

#ifdef DebugSwitches
  Serial.print(F("Display adress: "));
  Serial.println(DISPLAY_ADDRESS, HEX);
  Serial.print(F("Portexpander adress: "));
  Serial.println(PORT_EXPANDER_ADDRESS, HEX);

  Serial.print(F("Refsw: "));
  Serial.print(FY_Switches.getAnalogValue(Switches::Id::REF));
  Serial.print(F("  "));
  Serial.println(FY_Switches.getDigitalValue(Switches::Id::REF), DEC);

  Serial.print(F("TrimswL: "));
  Serial.print(FY_Switches.getAnalogValue(Switches::Id::TRIM_LEFT));
  Serial.print(F("  "));
  Serial.println(FY_Switches.getDigitalValue(Switches::Id::TRIM_LEFT), DEC);

  Serial.print(F("TrimswR: "));
  Serial.print(FY_Switches.getAnalogValue(Switches::Id::TRIM_RIGHT));
  Serial.print(F("  "));
  Serial.println(FY_Switches.getDigitalValue(Switches::Id::TRIM_RIGHT), DEC);
#endif

  printFirmwareInfo();

  Serial.println(F("init done "));
}

void loop()
{
  FY_uart.update();

  /*
  FY_Keyboard.Update();
  FY_Switches.update();
  FY_motor.Update();
  FY_display.update();
  */
}

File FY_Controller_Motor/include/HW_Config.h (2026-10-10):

#pragma once

// HW_Config.h
// Fixed hardware configuration of the FY controller.

#include <Arduino.h>

// I2C hardware addresses
constexpr uint8_t DISPLAY_ADDRESS = 0x3C;
constexpr uint8_t PORT_EXPANDER_ADDRESS = 0x20;

// DESIGN PROPOSAL — PCB variant detection (not implemented yet):
// Keep one firmware for both controller PCB variants by assigning the I2C
// port expander a different hardware address on each variant.
// - Existing PCB: keep the currently configured expander address (0x20).
// - Stepper-driver PCB: use a distinct address (for example 0x21), set by
//   the expander's address pins and verified against the actual wiring.
// At startup, probe the known variant addresses and select the PCB profile.
// Only the stepper-driver profile may configure/use the three Arduino pins
// connected to the driver's step-resolution inputs; those pins remain unused
// on the existing PCB. No address probing result must be treated as a valid
// variant unless the expected expander is actually detected.

// Arduino Nano hardware: I2C pins are fixed.
constexpr uint8_t I2C_SDA_PIN = A4;
constexpr uint8_t I2C_SCL_PIN = A5;

// Switch IDs
constexpr uint8_t SWITCH_REF_ID         = 0x01;
constexpr uint8_t SWITCH_TRIM_LEFT_ID   = 0x02;
constexpr uint8_t SWITCH_TRIM_RIGHT_ID  = 0x03;
constexpr uint8_t SWITCH_TIMING_BELT_ID = 0x04;

// Analog channels for switches
constexpr uint8_t NO_ANALOG = 0xFF;
constexpr uint8_t SWITCH_REF_A         = NO_ANALOG;
constexpr uint8_t SWITCH_TRIM_LEFT_A   = NO_ANALOG;
constexpr uint8_t SWITCH_TRIM_RIGHT_A  = NO_ANALOG;
constexpr uint8_t SWITCH_TIMING_BELT_A = NO_ANALOG;

// Digital pins for switches
constexpr uint8_t SWITCH_REF_D         = PB1; // D09
constexpr uint8_t SWITCH_TRIM_LEFT_D   = PB2; // D10
constexpr uint8_t SWITCH_TRIM_RIGHT_D  = PB3; // D11
constexpr uint8_t SWITCH_TIMING_BELT_D = PB4; // D12

// Motor control pins
constexpr uint8_t MOTOR_PWM_PIN    = PD3; // white wire
constexpr uint8_t MOTOR_DIR_PIN    = PD4; // yellow wire
constexpr uint8_t MOTOR_ENABLE_PIN = PD2; // blue wire

// Virtual pins for the I2C port expander.
// Values >= 100 avoid conflicts with normal Arduino pins.
constexpr uint8_t BUTTON_STOP  = 100;
constexpr uint8_t BUTTON_GO    = 101;
constexpr uint8_t BUTTON_LEFT  = 102;
constexpr uint8_t BUTTON_RIGHT = 103;
constexpr uint8_t LED1 = 104;
constexpr uint8_t LED2 = 105;
constexpr uint8_t LED3 = 106;
constexpr uint8_t LED4 = 107;

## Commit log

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2026-09-13 Add SystemStatus and UART response/CRC support
    Introduce FY_SystemStatus (SystemStatus.h) and update UART interfaces to use it. Implement UART response buffering (setResponse/sendResponse), CRC calculation and check (Calc_CRC/Check_CRC), and adapt UART context fields. Adjust protocol: STATUS_Position response length increased to 4 and telegramLength comment clarified. Add main.cpp skeleton to initialize and run UART and system state. Misc: minor fixes and refactors in UART.cpp and UART.h to support the new behavior.
    #6
    #7
    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
    [UART.cpp, main.cpp]
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2026-09-14 Use constexpr for pins; add system & UART stubs
    Replaced preprocessor #defines with typed constexpr for switches, analog/digital pins, motor pins, virtual buttons and LEDs; added Arduino.h include and a DebugSwitches placeholder. Extended system status structures by adding FY_System_Error_t, reorganizing FY_SystemStatus_t and introducing FY_Movement (position/speed range and reference flag). UART header gained CheckError/CheckBusy/SetCommand declarations; UART.cpp moved to lib/UART and contains stub implementations and many handler skeletons with added response calls. Minor refactor and relocation only.
    feat: #13 #6
2026-09-14 UART/protocol: add NACK, refactor handlers & docs
    Add STATUS_NACK and a FY_Trak_t struct; improve UART header comments and error-flag docs. Document and expand CommandBuffer/ResponseBuffer fields, add receive-state commentary, and clarify CRC helpers. Rename/standardize handler names (Handle_Busy -> handle_Busy, add handle_ACK) and add corresponding stubs in UART.cpp. Remove an unused Protokoll include from UART.cpp. These changes are primarily refactors and documentation improvements plus small API renames for UART command handling.
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2026-09-15 Refactor motor enums and add Timer1 support
    Convert MotorState_t and MotorProfile_t to scoped enum class and update all state checks. Widen Profilelement_t::Accel to uint16_t and reorganize private members. Add Timer1 initialization/start/stop routines, ISR stub, movement profile array, timer/profile limits and related constants. Refactor setJob signature/implementation, fix various return/semicolon issues, and small cleanup (Stop now writes ENA pin). Prepares code for timer-driven step generation and clearer state handling.
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2026-09-17 Add track types and update UART/Motor interfaces
    Introduce explicit track types and reference state handling, and adapt UART/Motor interfaces accordingly.
    - FY_System.h: add REF system state, reference error flag, fix Refrence -> Reference, add FY_Track enum and FY_Track_t struct (replacing previous uint8_t track fields) and explanatory ASCII diagram.
    - Motor/Motor.h: cast SPEED_TO_TIMER results to uint16_t for TIMER_V_MIN/TIMER_V_MAX.
    - UART/UART.h: update UART_Context_t to use FY_Track_t* (Track_INFO) and adjust field names/spacing.
    - UART/UART.cpp: use systemStatus->error in handleGetError, return Track_INFO in handleGetTrack, add a skeleton implementation and validation checks for handl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
2026-09-17 Implement motor movement profile calculation
    Add movement-profile support: introduce MM_TO_STEPS helper, MotorProfileParam_t and default _ProfileParam parameters in Motor.h; fix small typos and add documentation/ASCII diagrams. Rename placeholder calcprofil to calcProfile and implement profile algorithm in motor.cpp that splits a requested distance into ACC1/ACC2/KONST/BRE1/BRE2/POSI regions, reserves POSI/KONST minima, handles very short distances by using V_MIN, and corrects quantization remainder by adding it to POSI. Changes touch FY_Controller_Motor/lib/Motor/Motor.h and motor.cpp.
2026-09-17 Motor: fix profile params, job and prepare logic
    Normalize config macros (POS_MIN, KONST_MIN), add a shared MotorJob_t and remove duplicate definitions, and expose setJob declaration. Fix command handling (use prepareRight for CMD_RIGHT), correct method signatures (Motor::prepareParameter), add missing return in Reference(), and correct motor profile calculations to use _ProfileParam and Motor_profil. Also set _TimerValid and tidy related returns. These changes address compile issues and correct motor profiling/command handling logic.
    feat: #45
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2026-09-18 Refactor UART command handling, CRC and timeouts
    Replace the previous CMD_valid boolean with a UART_CommandStatus_t enum and centralize command status handling. Rework the receive state machine (FindCommand, ReadData, CheckCRC) to support inter-byte timeouts (UART_TIMEOUT_US) and only decode when a command is valid. Implement CRC calculation and optional RX CRC checking (UART_USE_RX_CRC) in Check_CRC/Calc_CRC. Add commandStatus field, getCommandStatus() and clearCommandStatus(), plus lastByteTime tracking. Update various places to set status values (CMD_INVALID, DATA_INVALID, CRC_INVALID) instead of the old flag. Improvements focus on robustness of UART telegram parsing and error reporting.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
2026-09-18 Fix UART command decoding & Busy handling
    Normalize formatting and switch spacing in UART.cpp. Change decodeImmediate logic to call handle_Busy() and return when systemStatus==Busy (preventing execution while busy) instead of the previous inverted branch. Clean up decodeCommand/decodePriority switch formatting, add a default case break in decodePriority, and tidied minor whitespace. No changes to individual command handlers.
    feat : #53
2026-09-18 Gate UART processing on commandReady
    The UART handler now waits for a fully validated command before decoding and responding. After CRC validation, the handler sets commandReady, and clears it after processing so the next telegram is only accepted once the current one has been handled. This avoids processing stale or overlapping UART commands.
    feat: #53
2026-09-18 Use CommandBuffer.status; improve UART timing
    Prevent re-entrancy by returning early when commandReady is set. Increase timeout resolution by using micros() instead of millis() for lastByteTime. Switch get/clear command status access to CommandBuffer.status and remove the redundant commandStatus member. Small whitespace tidy-ups.
    close: #53
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2026-09-19 Fix UART motor commands and NACK ID
    Correct the NACK status byte to a unique value and re-enable UART SetCommand() dispatch in the command handlers so valid motor commands are actually executed. The motor state machine now includes a reference-run marker for the CMD_REFERENCE path.
    feat: #54 #75 #76
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2026-09-20 Fix motor defaults and position state
    This change replaces the old macro-based minimum-position constants with constexpr values, initializes the motor position as unknown to avoid invalid zero-state assumptions, and corrects the default profile values and member declarations. It also fixes the UART method declaration and includes the motor header in the main application startup.
    [main.cpp]
2026-09-20 Use MotorProfile_t and qualify getJobResult
    Update Motor.h to replace uint8_t _ProfileElement with a volatile MotorProfile_t to hold the full profile element and mark it volatile. Fix motor.cpp by qualifying getJobResult as motor::getJobResult() so the function is defined as the class member returning _JobResult. Changes made in lib/Motor/Motor.h and lib/Motor/motor.cpp.
    Feat: #14
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2026-09-20 Refactor PCF8574 init and button handling
    Define ON/OFF constants and move PCF8574 pinMode setup into init_extendeder(), ensuring input/output pins are configured before calling begin() and preserving the initialization error loop. Remove stray pinMode calls outside functions. Update read_buttons() to map LOW reads to ON/ OFF using the new constants and change OLED output to show "OFF" instead of "--". Minor whitespace/formatting cleanup.
    [main.cpp]
2026-09-20 Update button labels and expander outputs
    Replace generic K1..K4 labels with descriptive color labels (Rot, Blau1, Gruen, Blau2) and add expander.digitalWrite(...) calls for P3..P0 mapped to the inverted key states (!keyX). Comments added to clarify color mappings. This makes the display show meaningful names and drives the external expander pins so LEDs reflect button states.
    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
    [main.cpp]
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2026-09-21 Error eingebunden in main eigener Ordner
    #80
    [main.cpp]
2026-09-21 Rename light sensor pins and update labels
    Replace LS1/LS2/LS3 with descriptive names LSL, LSR and LSREF. Update digitalRead and pinMode usages and adjust OLED status labels to match the new identifiers (including K4 label tweak). This is a refactor only — no functional logic changes.
    [main.cpp]
2026-09-21 Remove Error.h from header; include in sources
    Remove the direct inclusion of Error.h from FY_System.h and instead include Error.h in the translation units that need it (FY_Controller_Motor/lib/Motor/motor.cpp and FY_Controller_Motor/lib/UART/UART.cpp). This reduces header coupling and potential circular dependencies while keeping Error definitions available where required.
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2026-09-22 Rename button API and add switch scaffolding
    The old Buttons library was removed and replaced with a Keyboard abstraction exposing button and LED IDs plus init/access helpers. A new Switches class was introduced with placeholder update/read implementations, and the Switches header was updated to include Arduino types and use consistent uint8_t-based IDs.
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2026-09-22 Resolve merge conflict and init keyboard
    Remove leftover merge conflict markers and duplicate Keyboard declaration in FY_Controller_Motor/src/main.cpp. Add FY_Keyboard.begin() to the system initialization and perform minor whitespace cleanup. This fixes build errors caused by the conflict markers and ensures the local keyboard is initialized at startup.
    [main.cpp]
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2026-09-22 Resolve merge conflicts in main.cpp init
    Remove leftover merge markers and unify initialization sequence in main.cpp. Instantiate FY_Keyboard with button/pin/address parameters, move FY_motor.begin() to initialization path, and remove large commented-out display/port-expander/system-error blocks. Cleans up duplicated calls and restores a coherent startup flow so keyboard and motor are initialized correctly.
    [main.cpp]
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2026-09-22 Replace Motor calcProfile test with sanity test
    Remove the detailed Motor::calcProfile unit test (FY_Controller_Motor/test/Motor/test_calcProfile.cpp) and add a minimal sanity test (FY_Controller_Motor/test/test_calcProfile/test_calcProfile.cpp) that verifies the test harness. The previous test validated step summation and profile symmetry; the new test only asserts true, simplifying the test suite (likely to isolate or avoid hardware-dependent Motor logic).
    feat #46
    [test_calcProfile.cpp]
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2026-09-23 test: fix calcProfile test includes (#46)
    [test_calcProfile.cpp]
2026-09-23 test: fix motor state assertions (#14)
    [test_State.cpp]
2026-09-23 test: fix setJob test dependencies (#54)
    [test_setJob.cpp]
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2026-09-25 Fix interactive button LED mapping test
    [main.cpp]
2026-09-25 Fix button LED mapping test and remove alive output
    [main.cpp]
2026-09-25 Fix mapping LED helper declaration
    [main.cpp]
2026-09-25 Fix mapping test debounce and slow LED cycling
    [main.cpp]
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2026-09-25 Fix PCF init and show button states on OLED
    [main.cpp]
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2026-09-25 Correct verified HW test button and LED mapping
    [HW_Test.h]
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2026-09-25 Fix HW test display and central IO handling
    [main.cpp]
2026-09-25 Fix red/green LED mapping
    [HW_Test.h]
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2026-09-25 Fix frequency selection and display state
    [main.cpp]
2026-09-26 Add HW IO state and step tuning
    This change centralizes hardware I/O into a shared HWIOState image, fixes the verified button/LED mappings, and adds adjustable step frequencies for the hardware test. It also exposes read_IO, init_step_timer, and set_step_frequency so the test logic can operate from a consistent hardware view and switch frequencies with BLUE 1/BLUE 2 while ENA is OFF.
2026-09-26 Adjust display timing and limit switch pins
    This change reduces the display refresh interval from 500 ms to 200 ms for faster UI updates. It also swaps the left/right limit switch pin assignments to match the intended hardware wiring in the test headers.
    [HW_Test.h]
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2026-09-26 test: stabilize end switch measurement capture
    [main.cpp]
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2026-09-26 fix: restore hardware test limit switch mapping
    [HW_Test.h]
2026-09-26 fix: correct enable polarity and step output
    [main.cpp]
2026-09-26 Swap limit pins, add measurement, fix ENA
    Corrects limit-switch pin assignments (LSL/LSR swapped), adds HWMeasurement struct with an extern volatile measurement and get_measurement() prototype to capture mechanism measurements, and fixes MOTOR_ENA output polarity in main.cpp (invert digitalWrite logic). Changes applied to FY_HW_TEST include/header and src/main.cpp to enable proper HW behavior and measurement support.
    [main.cpp]
2026-09-26 fix: align hardware test limit switch mapping
    [HW_Test.h]
2026-09-26 fix: use corrected limit switch mapping in ISR
    [main.cpp]
2026-09-26 Fix swapped LSL/LSR pin assignments
    Correct a typo in FY_HW_TEST/include/HW_TEST.h where the LSL and LSR pin constants were reversed. LSR is now set to 9 and LSL to 12 to match hardware labeling and prevent incorrect limit-switch behavior.
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2026-09-26 Introduce FastInputPin for limit sensors
    Add FastInputPin struct to group Arduino pin, inputRegister and mask; replace raw pin constants (LSR, LSL, LSREF, LS4) with FastInputPin instances in include/HW_TEST.h. Update FY_HW_TEST/src/main.cpp to use .pin for digitalRead() and pinMode() so normal code stays compatible while Timer1 ISR can use inputRegister/mask for fast reads. This keeps physical sensor definition and fast ISR access colocated.
    [main.cpp]
2026-09-26 fix: correct end switch polarity in ISR
    [main.cpp]
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2026-09-26 fix: correct LSR D9 register mapping
    [HW_Test.h]
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2026-09-26 fix: complete hardware test release behavior
    [main.cpp]
2026-09-27 Tune hardware test timing and limits
    Update the hardware test configuration to use a wider, faster step-frequency range and a 20 ms switch polling interval. Correct the LSR input mapping for the Arduino Nano ATmega328P and add a MAX_ALLOWED_STEPS guard to cap measurement length safely.
    The step timer initialization now resets to a known safe measurement state instead of zeroing the total length, preventing runaway step tracking. This commit also includes a small comment cleanup and disables an unused helper declaration to keep the firmware build clean.
    feat : #101 #84
    [HW_Test.h, main.cpp]
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2026-09-27 Fix include guard directive in HW_Test.h
    ident 2
    [HW_Test.h]
2026-09-27 Fix invalid header directive
    The header file had a malformed preprocessor line (`#HW_test.h`) instead of a C++ comment. This change corrects it to `// HW_test.h`, preventing invalid preprocessing and allowing the header to compile cleanly.
    [HW_Test.h]
2026-09-27 Guard startup limit switches with enable state
    Prevent the left/right movement buttons from bypassing the startup end-stop protection unless the system is enabled. The guard now requires both the relevant limit switch and the enable flag to be true before breaking out of the move logic.
    feat: #84
    [main.cpp]
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2026-09-30 fix: #102 VMin bei kurzen Profilen beibehalten
    [main.cpp]
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2026-09-30 fix: #102 kurze Profile bei VMin starten
    [main.cpp]
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2026-09-30 Fix Timer1 prescaler selection to /256
    [main.cpp]
2026-09-30 Fix constant-speed phase to hold reached speed
    [main.cpp]
2026-09-30 Fix profile loader cleanup
    [main.cpp]
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2026-10-01 Fix #27: align REF state machine with motion state visibility
    [main.cpp]
2026-10-01 Fix #27: start REF motion in ISR
    [main.cpp]
2026-10-01 Fix #27: keep REF enable under GO/STOP control
    [main.cpp]
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2026-10-01 Fix reference flag edge order for reverse measurement
    [main.cpp]
2026-10-01 Fix duplicate reference state declaration
    [main.cpp]
2026-10-01 Fix REF state switch after bidirectional measurement
    [main.cpp]
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2026-10-01 Correct measured track positions BG4 and BG5
    [main.cpp]
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2026-10-01 Implement short reference run
    [main.cpp]
2026-10-01 Move to BG3 after short reference
    [main.cpp]
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2026-10-01 Fix hardware test position initialization
    [main.cpp]
2026-10-01 Fix init_step_timer position initialization
    [main.cpp]
2026-10-01 Fix left limit position reference
    [main.cpp]
2026-10-01 Fix short reference return to BG3 from left end position
    [main.cpp]
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2026-10-02 fix: add motor direction state for ISR (#104)
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2026-10-02 Issue #53: integrate BabelFish with UART receive lifecycle
2026-10-02 Issue #53: make UART the single serial receive owner
    [main.cpp]
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2026-10-05 first misra report and updaten Git ignore MISRA / Cppcheck als automatischer Prüfcheck Fixes #111
    [misra.csv]
2026-10-05 fix: make button initial state explicit for MISRA #112
2026-10-05 fix: remove Arduino macros from initializer lists #112
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2026-10-05 ftest after first fix Fixes #112
    [misra.csv]
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2026-10-05 refactor: stop passing fixed I2C pins #112
    [main.cpp]
2026-10-05 next problem
    [misra.csv]
2026-10-05 fix: filter MISRA report instead of invalid enable level #111
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2026-10-05 refactor: separate fixed hardware configuration #112
    [HW_Config.h]
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2026-10-06 Fix track selection and timing profile
    Adjusted the profile timing intervals for accel2 and brake1 from 1 to 2, and corrected the track selection wraparound logic so the previous/next track buttons move in the intended direction.
    [main.cpp]
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2026-10-06 fix: expose protocol config and initialize PCF8574 #111
    [main.cpp]
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2026-10-08 STRUCT: add Error class skeleton and begin hook (#50)
    [main.cpp]
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2026-10-08 REFACTOR: connect UART to central Error
    [main.cpp]
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2026-10-09 FEAT: port three-slot central error storage to FY_Controller_Motor
2026-10-09 REFACTOR: add motor error definitions to active branch
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2026-10-09 FEAT: route UART errors and GET_ERROR through central Error
2026-10-09 FEAT: initialize central Error handler in controller
    [main.cpp]
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2026-10-10 Add Commands U6 – UART Telegrammdefinitionen und Command-Parameter konsistent machen Feat: #58 UART Handler – CMD_GET_TRACK definieren Fixes #117
    [misra.csv, misra_full.csv]
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2026-10-11 Fix motor Timer1 frequency conversion and use /1024
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2026-10-19 fix(esp32): expose shared protocol header to PlatformIO library build
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2026-10-19 docs(esp32): assign Error ownership to Huginn and safety handling to Muninn (#162)
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2026-10-19 docs(esp32): replace Nano-only system duplicate with ESP32 living docs (#162)
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2026-10-20 Add library paths to VS Code config
    Add UART, Motor, Error, Keyboard, and Switches library directories to the PlatformIO include and browse paths.
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2026-10-20 fix(esp32): include motor GPIO configuration in Muninn mock (#156)
2026-10-20 fix(esp32): use shared FY error locations and preserve motor responses under queue backpressure (#156)
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2026-10-20 fix(esp32): keep A4988 EN disabled throughout startup blink test (#156)
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2026-10-20 fix(esp32): run STEP/DIR boot blink before UART tasks to prevent GO-enable race (#156)
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2026-10-20 fix(esp32): initialize microstep pins before startup STEP/DIR check and tasks (#153)
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2026-10-20 fix(esp32): make repeated GO enable idempotent so active STEP pulses are undisturbed (#153)
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2026-10-20 docs(esp32): replace 64-step LEFT/RIGHT guide with MOVE byte format and safe 1000-step bench guide (#153)
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2026-10-20 test(esp32): allow 10000-step MOVE for manual STOP verification with loose motor (#153)
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2026-10-20 docs(esp32): correct validated MOVE status and request-response-only completion model (#154)
2026-10-20 fix(esp32): latch STOP by default after every POR/reset until explicit release (#154)
2026-10-20 fix(esp32): remove startup STEP/DIR blink now POR begins STOP-locked (#155)
2026-10-20 fix(esp32): preserve namespace boundary after removing startup LED pulses (#155)
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2026-10-20 fix(esp32): match Nano effective ramp intervals ACC1/ACC2/BRE1/BRE2 = 1/2/2/1 (#153)
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2026-10-20 fix(esp32): keep timer reload constexpr GNU++11 compatible for PlatformIO (#153)
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2026-10-20 docs: update FY roadmap with ESP32 command/function traffic-light gates and prepare issue mapping
2026-10-20 docs: replace stale Nano UART cheat sheet with ESP32 command traffic lights and prepare status
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2026-10-21 docs(esp32): establish issue-led module documentation and verification review
    Centralize module docs, archive Nano working diagrams, reconcile current UART/motor architecture, track open issue-code deltas, and add a separate Cppcheck/MISRA-oriented PlatformIO target.
2026-10-21 docs(esp32): fix relative HW-test links and empty-module references
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2026-10-21 docs(roadmap): end Nano product development and replace outlook with ESP32 plan
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2026-10-23 fix(hw3): STEP auf G27 und ENABLE auf G25 konfigurieren, LED-Polaritaet dokumentieren
2026-10-23 feat(hw3): SLEEP/RESET G32 im Setup vor Motor-GPIOs auf LOW setzen
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2026-10-23 docs(hw3): alle vier LEDs aktiv LOW und einmaliges SLEEP-Wake korrigieren
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2026-10-25 feat(ref): port Nano short and long reference stages to Muninn
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2026-10-25 feat(ref): automatically move to track 3 after short and long reference
2026-10-25 fix(uart): banner reflects real REF and RAM-only calibration
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2026-10-25 fix(ref): C++ default argument only in Motor declaration
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2026-10-25 fix(ref): follow Nano reference transitions, speed up coarse search, diagnose failure stage
2026-10-25 fix(motor): restore Nano 1/8 microstepping for initialization, reference and position moves
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2026-10-25 fix(motor): set microstepping only in init; reject runtime mode switches
2026-10-25 refactor(motor): move fixed microstep config and movement declarations into Motor.h
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2026-10-25 fix(build): replace stale FY_Move.h include with Motor definitions
2026-10-25 fix(build): expose move payload decoder declaration to UART
2026-10-25 fix(build): provide external move decoder definition from Motor.cpp
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2026-10-25 docs: correct measured track position units to 1/8 step
2026-10-25 refactor(motor): reuse existing SET_TRACK preparation and profile; real REF replaces fake permission
2026-10-25 fix(motor): SET_TRACK exclusively requires physical reference, never fake calibration
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2026-10-25 docs(esp32): correct active Switches integration and tested reference paths
2026-10-26 fix(motor): stop STEP on destination endstop during all motions
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2026-10-26 feat(nvm): load calibration/tracks, seed missing track defaults, persist measured REF after BG3
2026-10-26 fix(nvm): gate movement on corrupt segments, preserve persistent calibration delta baseline
2026-10-26 fix(esp32): avoid Arduino binary.h B1 macro collision in ParamId
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2026-10-26 Revert incomplete motor parameter header until coherent implementation
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2026-10-31 Keyboard: adopt U8g2 5x8 OLED driver in cleanup
    Replace Adafruit GFX/SSD1306 with U8g2 5x8, retain 128x32 I2C 0x3C and R2 rotation. Update keyboard docs. Display readability tested; full keyboard regression still outstanding (#177).
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2026-10-31 Docs: document actual Error storage, GET_ERROR scope, NACK separation and data flow
2026-10-31 Docs: verify Error cleanup with successful build and UART parser-error regression
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2026-11-01 fix(esp32): HELP verweist auf UART-Spickzettel in main (Refs #172)
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2026-11-01 fix(UART): avoid narrowing in keyboard STATUS bytes refs #171
    Explicit uint8_t conversion of bool Keyboard_isAvailable() for STATUS_SYSTEM and STATUS_KEYBOARD. No change in response values or length. Build verification to follow.
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2026-11-02 fix(http): validate full track geometry and refuse preselection during reference
2026-11-02 fix(web): dim stage when live physical position is unknown
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2026-11-02 feat(web): enable controlled HTTP test buttons, short/long REF and diagnostics navigation
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2026-11-06 ota: add guarded browser upload, inactive slot check, image validation and reboot
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2026-11-06 uploader: wait for physical STOP approval after build to avoid 120s arm expiration
